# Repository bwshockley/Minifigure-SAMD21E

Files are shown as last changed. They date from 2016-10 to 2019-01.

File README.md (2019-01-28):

# Minifigure-SAMD21E
SAMD21E based Minifigure shaped development board.

## About
This circuit board was designed as a fun project for a SAMD21E microcontroller based development board.  The circuit design follows the recommended design from the SAMD Datasheet - including section 39. Schematic Checklist.  The USB protection may be overkill, but it is complete.  I made this just for fun - I am not going to provide any special support, but always welcome recommendations, suggestions, and ideas for improvements.  You are free to take it and run with it, but do not sell this design.

Order boards here:
Board 1: Stand alone - haven't tested, but should soon. [OSHPark](https://oshpark.com/shared_projects/Wh7NwFnv)

Board 2: This does not have a native USB or programming port - I am developing a backpack for it.  Will share backpack. [OSHPark](https://oshpark.com/shared_projects/W2bUXtFr)

MINI SAM TQFP SIMPLE - This version is more friendly to hand soldering with a TQFP SAMD21E chip.  USB protection and filtering removed, reset debounce removed.  [OSHPARK](https://oshpark.com/shared_projects/yFTXsDW0)

MINI SAM TQFP 1.27 SIMPLE - This version retains the TQFP SAMD21E chip, but on the back instead of the tiny 8-pin connector - I've replaced it with a 1.27mm pitch SMT connector.  Still trying to retain a "backpack" idea for add-on boards.  [OSHPARK](https://oshpark.com/shared_projects/vt6FGicv)

MINI SAM TQFP 2.54 BB (BreadBoard or Protoboard) - This version changes the rear once more to a 2.54mm pitch SMT setup for a protoboard friendly design. [OSHPARK](https://oshpark.com/shared_projects/SMD5UkUu)

Mini SAM - Protoboard - TQFP - 2017-01-17-00 - This version is similar to the other BB version, but has some refinements to layout and includes options for the onboard LED (Basic LED or the WS2812B), a plain button, and other enhancements.  [OSHPARK](https://oshpark.com/shared_projects/IhRoccbe)

Mini SAM 2017/01-001 - Latest version with minor changes and enhancements.  Once this version passes validation and verification, I will most likely archive other versions.  Details on [OSHPARK](https://oshpark.com/shared_projects/dv4tvRPH) and [here](https://github.com/bwshockley/Minifigure-SAMD21E/tree/master/board/2017/01).

----------------------------------

## Etc
The board passes all DRC for OSHPark manufacturing and should pass for most other manufacturers as well - I kept most routes, vias, etc larger than minimums and allowed plenty of space where I could.  I have tested many of these boards and all features work as designed.

## BOM
*The BOM listed at mouser is for the Mini SAM - Protoboard - TQFP - 2017-01-17-004 board.  It is a good place to start, but keep in mind you may want to change or leave out items you don't want.*

The schematic has all items listed and values and should be easily sourced.  Additionally, I have setup a [project on mouser.com that can be found here.](http://www.mouser.com/ProjectManager/ProjectDetail.aspx?AccessID=328cc4307e)  The BOM through mouser is roughly 12 USD at this time (Oct 2016).  It does not include the WS8212B 3535 LED - these can be sourced from [Adafruit](https://www.adafruit.com/products/2659) or eBay among others.  The LED does not need to be populated for the board to function, but it is fun.

## Firmware
I plan on trying to implement both Arduino and possibly Micropython on this board, but need some significant help with this.  I will update as I can.

In order to test my prototype board, I loaded the Arduino Zero bootloader, but changes the PortA pin 14 for PostA Pin 27.  Nothing else is fucntional yet - it was a bad hack to get access to the WS2812 LED for the time being and to prove to myself the board will work in theory.

(01-20-2017) FIRMWARE has been updated and almost complete.  I'm working through the last bit of verification and validation now.  Firmware and Arduino files are available in the arduino folder.  In order to burn the bootloader, the Atmel SAM-BA In-System Programmer must be installed first.

## License
Hardware - CC BY-NC 4.0 - See License file.

Software
Copyright (c) 2017 Benjamin Shockley

Permission is hereby granted, free of charge, to any person obtaining a copy
of this software and associated documentation files (the "Software"), to deal
in the Software without restriction, including without limitation the rights
to use, copy, modify, merge, publish, distribute, sublicense, and/or sell
copies of the Software, and to permit persons to whom the Software is
furnished to do so, subject to the following conditions:

The above copyright notice and this permission notice shall be included in all
copies or substantial portions of the Software.

THE SOFTWARE IS PROVIDED "AS IS", WITHOUT WARRANTY OF ANY KIND, EXPRESS OR
IMPLIED, INCLUDING BUT NOT LIMITED TO THE WARRANTIES OF MERCHANTABILITY,
FITNESS FOR A PARTICULAR PURPOSE AND NONINFRINGEMENT. IN NO EVENT SHALL THE
AUTHORS OR COPYRIGHT HOLDERS BE LIABLE FOR ANY CLAIM, DAMAGES OR OTHER
LIABILITY, WHETHER IN AN ACTION OF CONTRACT, TORT OR OTHERWISE, ARISING FROM,
OUT OF OR IN CONNECTION WITH THE SOFTWARE OR THE USE OR OTHER DEALINGS IN THE
SOFTWARE.

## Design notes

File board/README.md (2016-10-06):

#EAGLE Files
At this time I only have EAGLE files for the Minifigure Board.  If someone wants to convert them to KiCAD, I'd be happy to add those files to the repository.

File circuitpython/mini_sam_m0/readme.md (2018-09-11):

# Mini Sam M0 CircuitPython Firmware

## Source Files
Source Files Included:
- board.c
- mpconfigboard.h
- mpconfigboard.mk
- pins.c

Use these files and https://circuitpython.readthedocs.io/en/latest/ports/atmel-samd/README.html to build firmware.

## Built Firmware
- firmware.bin
- firmware.uf2

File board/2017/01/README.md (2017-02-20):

##Board 2017/01-002

This is a LEGO Minifigure sized development board using an Atmel SAMD21E 32-Bit ARM chip. I basically followed the recommended layout/setup from the SAMD21 spec sheets.

Included on Mini SAM is a WS2812B LED (STATUS) connected to PIN 27, a 0603 LED (L) connected to PIN 15, a reset button (SW1) with circuitry per datasheet connected to !RESET, and a user programmable button (SW1) that is active HIGH connected to PIN 28. The 0603 LED is connected in series with a 1Kohm resistor, part of R1, and care should be taken when selecting an 0603 LED such that at a supply of 3.3V, no more than 5mA is required.

Programming port (PROG) is a basic 10-pin SWD for ARM based processors, which is a 2x5 1.27mm pitch connector. The SWD line is pulled up with a 1Kohm resistor, part of R1.

The SDA/SCL pins are pulled high with 4.7KOhm resistors, R2, per SDA/SCL recommendations.

The voltage regulator is an MCP1700 (IC1) which is rated at 250mA at 3.3V. Plenty of current for the SAMD21E and a few other accessories such as the WS2812B.

This version has SMT layout for two single row 2.54mm pitch headers on the back. It is designed to be protoboard friendly and when populated the headers are the same width as a DIL package (7.62mm or .3") and span the center of a protoboard.

PINs 27 and 28 are not connected to the headers - due to lack of space - but instead have two pads near the bottom of the board. Reminder: PIN 27 is connected to the on-board WS2812B and PIN 28 is connected to the on-board BUTTON.

The AREF PIN - PIN AREF - has a pair of decoupling/filtering capacitors (C6, C11).

The micro-USB connector has an RC filter (R6, C13) between the case/shield of the connector and GND. If left un-populated the case/shield is an open circuit - which is the next best option. Also included is space for a USBLC6-2 (IC2) ESD protection circuit. You can bypass it by jumping PAD 1 to 6, and PAD 3 to 4, leaving the middle two PADs alone of the layout for IC2.

I have put together a sample BOM via Mouser.com which I’m including here. It can be used as a reference. Items that do not need to be populated to work: SW2812B 3535 LED, 0603 LED, SW2 (BUTTON). The SW2812B is not in the Mouser BOM - due to lack of parts. I would suggest not purchasing the 2.54mm pitch SMT male headers from Mouser, as you can find this much cheaper elsewhere. Mini SAM requires (2) 11-PIN headers. I suggest buying breakaway headers in 25-50 PIN lengths.

Arduino FIRMWARE/BOOTLOADER is complete, but I’m still testing all functions. So far all PINs work in digital setup and all analog PINs work accordingly. ANALOG and special function pins (MOSI, SDA, SCK, etc) can be accessed in Arduino by their name.

##Board 2017/01-010

This is a LEGO Minifigure sized development board using an Atmel SAMD21E 32-Bit ARM chip.  I basically followed the recommended layout/setup from the SAMD21 spec sheets.

Included on Mini SAM is a WS2812B LED pad connected to PIN 27, a 0603 LED connected to PIN 15, a reset button with support components per the datasheet, and a generic button that is active HIGH on PIN 28. The 0603 LED is connected in series with a 1Kohm resistor, part of R1, and care should be taken when selecting an 0603 LED such that at a supply of 3.3V, no more than 5mA is required.

Programming port is a standard10-pin SWD for ARM based processors, which is a 2x5 1.27mm pitch connector.  The SWD line is pulled up with a 1Kohm resistor, part of R1.  In the BOM, either purchase the 2x5 straight pin connector OR the 2x5 POGO connector and do not populate board.

The SDA/SCL pins are pulled high with 4.7KOhm resistors, R2, per SDA/SCL recommendations.

The voltage regulator is an AP2112K-3.3V which is rated at 600mA at 3.3V.  Plenty of current for the SAMD21E and a few other accessories such as the WS2812B.

This version has SMT layout for two single row 2.54mm pitch headers on the back.  It is designed to be protoboard friendly and when populated the headers are the same width as a DIL package (7.62mm or .3") and span the center of a protoboard.

PINs 27 and 28 are not connected to headers - due to lack of space - but instead have two pads near the bottom of the board.  PIN 27 is connected to the on-board WS2812B.  PIN 28 is connected to the on-board BUTTON.

The Analog Reference (PIN AREF) - has a pair of decoupling/filtering capacitors.

The micro-USB connector has an RC filter between the case/shield of the connector and GND.  If R6 and C13 are left un-populated the case/shield is an open circuit - which is the next best option.  Also included is space for a PRTR5V0U2X ESD protection circuit on USB Data lines.  This may also be left un-populated and USB will function normally.

I have put together a sample BOM via Mouser.com which I'm including here.  It can be used as a reference.  Optional, but highly recommended components: SW2812B 3535 LED, 0603 LED, SW2 (BUTTON), R4, R5, R6, C13, and PRTR5V0U2X.  R1 is for the 0603 LED and SWCLK - If not populating the 0603 LED this *may* be left un-populated as well and programming via SWD should still work as I've seen other boards without the 1Kohm resistor on SWCLK.  R2 is the 4.7Kohm pull-up resistor pair for SDA/SCL.  Many breakout boards using chips that run off SDA/SCL typically come with the 4.7Kohm pull-up resistor pair included - as such it may not be needed on Mini SAM - but it is included for ease of future components.  Please review the schematic for additional details and be aware that the BOM on Mouser.com may be out of date.  *The SW2812B is not in the Mouser BOM - due to lack of parts.*

[Mouser BOM](http://www.mouser.com/ProjectManager/ProjectDetail.aspx?AccessID=fc486f90dc)

I would suggest not purchasing the 2.54mm pitch SMT male headers from Mouser, as you can find this much cheaper elsewhere.  The best I could find on Mouser is (2) 5-Pin and (2) 6-Pin headers.  Mini SAM requires (2) 11-PIN headers.  I suggest buying breakaway headers in 25-50 PIN lengths.

Arduino FIRMWARE/BOOTLOADER is complete, but I'm still testing all functions.  So far all PINs work in digital setup and all analog PINs work accordingly.  ANALOG and special function pins (MOSI, SDA, SCK, etc) can be accessed in Arduino by their name.

Please check my Github for the latest design files and bootloade/firmware.

More details can be found on [Github](https://github.com/bwshockley/Minifigure-SAMD21E)

##Board 2017/01-012
Same as 2017/01-010 with minor cosmetic changes.

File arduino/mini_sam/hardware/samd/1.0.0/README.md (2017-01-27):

# Arduino Core for SAMD21 CPU - Mini SAM Specific

This repository contains the source code and configuration files of the Arduino Core
for Atmel's SAMD21 processor used for the Mini SAM board.

## Installation on Arduino IDE

Copy the directory [mini_sam](https://github.com/bwshockley/Minifigure-SAMD21E/new/master/arduino) to your Arduino packages directory.

## Support

Support for this repository is provided via the [Issues](https://github.com/bwshockley/Minifigure-SAMD21E/issues) page.

## Bugs or Issues

If you find a bug you can submit an issue here on github:

[https://github.com/bwshockley/Minifigure-SAMD21E/issues](https://github.com/bwshockley/Minifigure-SAMD21E/issues)

Before posting a new issue, please check if the same problem has been already reported by someone else
to avoid duplicates.

## Contributions

Contributions are always welcome. The preferred way to receive code cotribution is by submitting a 
Pull Request on github.

## License and credits

This core was developed for the Mini SAM development board and uses files and build tools from Arduino and Atmel.

```

  This library is free software; you can redistribute it and/or
  modify it under the terms of the GNU Lesser General Public
  License as published by the Free Software Foundation; either
  version 2.1 of the License, or (at your option) any later version.

  This library is distributed in the hope that it will be useful,
  but WITHOUT ANY WARRANTY; without even the implied warranty of
  MERCHANTABILITY or FITNESS FOR A PARTICULAR PURPOSE.
  See the GNU Lesser General Public License for more details.

  You should have received a copy of the GNU Lesser General Public
  License along with this library; if not, write to the Free Software
  Foundation, Inc., 51 Franklin St, Fifth Floor, Boston, MA  02110-1301  USA
```

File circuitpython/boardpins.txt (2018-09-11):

PIN     mini_sam_m0
PA00		
PA01		
PA02    ~A0
PA03									
PB08	
PB09
PA04    ~A3
PA05    ~A4
PA06    ~A1
PA07    ~A2
PA08    ~A5
PA09    A6
PA10    D1 / TX
PA11    D0 / RX
PB10
PB11	
PA12	
PA13	
PA14    D14
PA15    LED / D15
PA16    MOSI
PA17    SCK
PA18    SS / D18
PA19    MISO
PA20		
PA21		
PA22    SDA
PA23    SCL
PA24									
PA25									
PB22						
PB23							
PA27    NEOPIXEL / D27
PA28    BUTTON / D28
PA29									
PA30
PA31

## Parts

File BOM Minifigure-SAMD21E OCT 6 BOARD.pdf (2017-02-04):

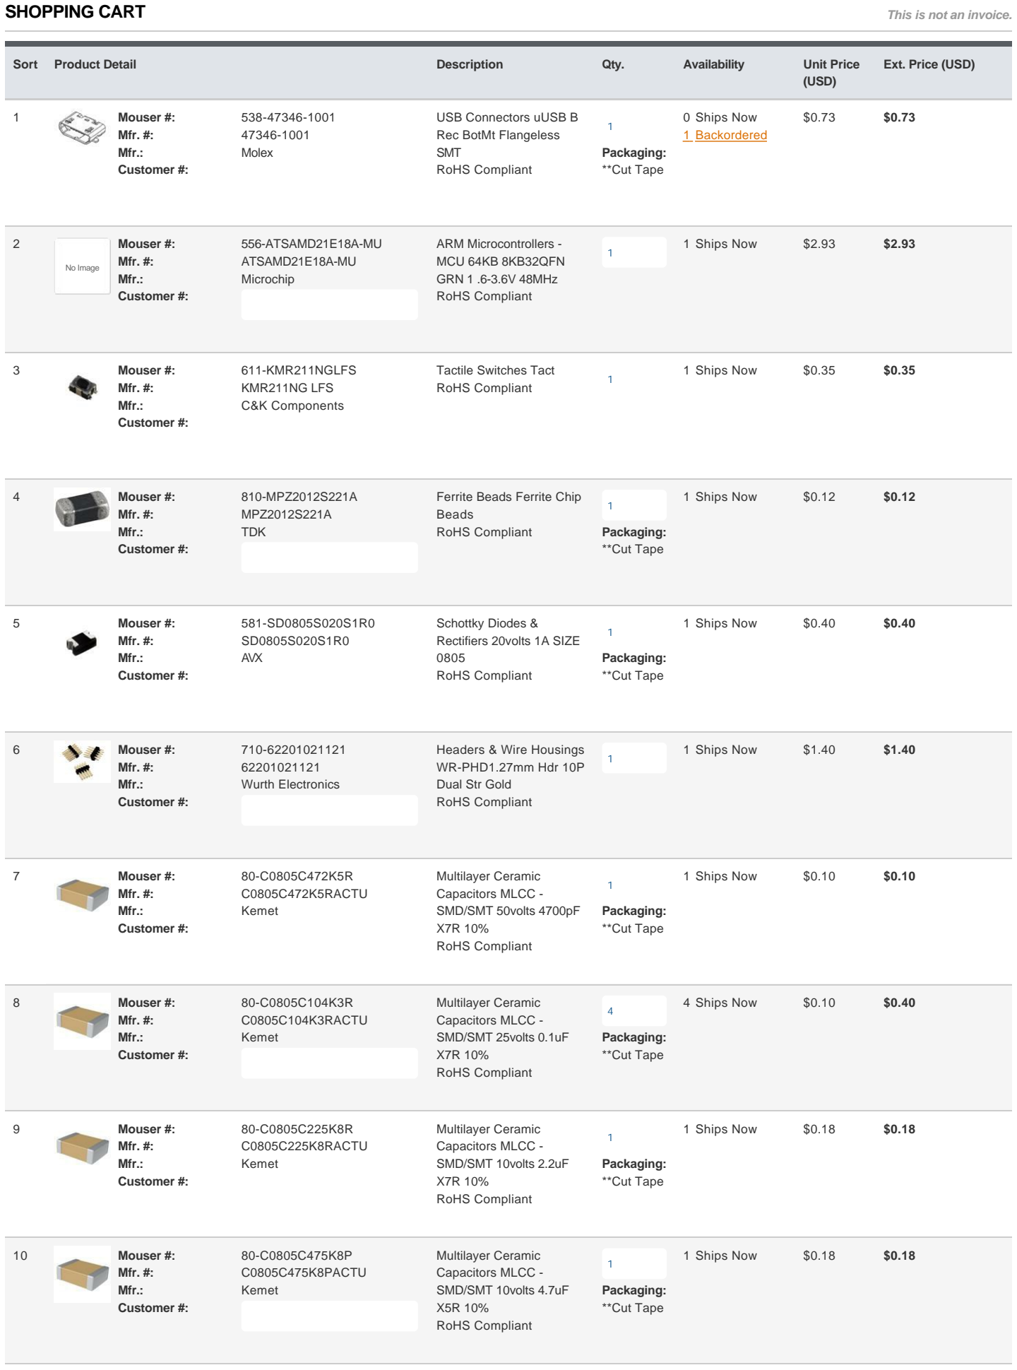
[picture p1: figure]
Sort; Product Detail; Description; Qty.; Availability; Unit Price; (USD); Ext. Price (USD); SHOPPING CART; This is not an invoice.; Mouser #:; Mfr. #:; Mfr.:; Molex; Customer #:; USB Connectors uUSB B; Rec BotMt Flangeless; SMT; RoHS Compliant; Packaging:; **Cut Tape; 0 Ships Now; 1 Backordered; No Image; 556-ATSAMD21E18A-MU; ATSAMD21E18A-MU; Microchip; ARM Microcontrollers -; MCU 64KB 8KB32QFN; GRN 1 .6-3.6V 48MHz; 1 Ships Now; 611-KMR211NGLFS; KMR211NG LFS; C&K Components; Tactile Switches Tact; 810-MPZ2012S221A; MPZ2012S221A; TDK; Ferrite Beads Ferrite Chip; Beads; AVX; Schottky Diodes &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

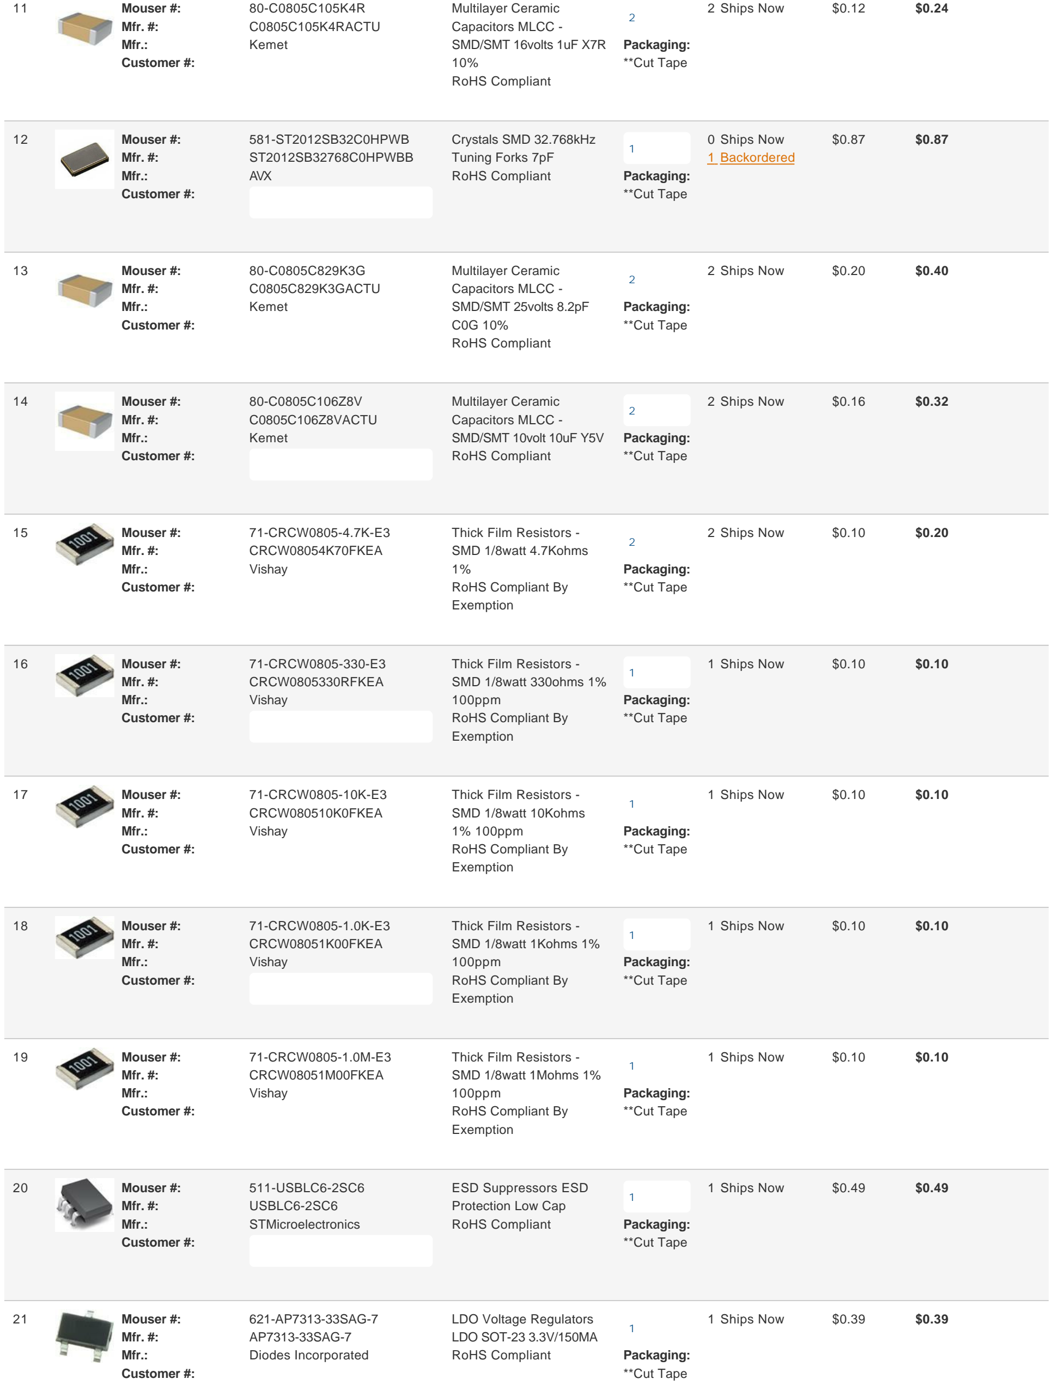
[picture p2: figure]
Mouser #:; Mfr. #:; C0805C105K4RACTU; Mfr.:; Kemet; Customer #:; Multilayer Ceramic; Capacitors MLCC -; SMD/SMT 16volts 1uF X7R; RoHS Compliant; Packaging:; **Cut Tape; 2 Ships Now; 581-ST2012SB32C0HPWB; ST2012SB32768C0HPWBB; AVX; Crystals SMD 32.768kHz; Tuning Forks 7pF; 0 Ships Now; 1 Backordered; C0805C829K3GACTU; SMD/SMT 25volts 8.2pF; C0805C106Z8VACTU; SMD/SMT 10volt 10uF Y5V; 71-CRCW0805-4.7K-E3; CRCW08054K70FKEA; Vishay; Thick Film Resistors -; SMD 1/8watt 4.7Kohms; RoHS Compliant By; Exemption; 71-CRCW0805-330-E3; CRCW0805330RFKEA; SMD 1/8watt 330ohms 1%; 100ppm; 1 Ships Now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

By submitting your order you agree to these terms and conditions. (http://www.mouser.com/saleterms) For additional information on availability, click on the Mouser Part #.

**All MouseReel™ items are noncancellable and nonreturnable.

Merchandise Total: | $10.10
Shipping Charge: | Estimate (http://www.mouser.com/EstimateShipping/ShippingEstimatorModal.aspx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)
Backorder Shipping: | Estimate (http://www.mouser.com/EstimateShipping/ShippingEstimatorModal.aspx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)

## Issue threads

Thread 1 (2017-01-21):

Beautiful Work

alwynallan, 2017-01-21:
It's the best thing shared on OSH Park recently. I hope there's a Kickstarter soon. An easy tool chain, like Teensyduino, would make it awesome, but I know it's a lot of work to create and maintain.

One little issue I noticed is the connection of the USB shield to ground. There's endless discussion in forums, with several camps:
  1. open circuit
  2. parallel RC to ground, typically 4.7nF and 1M
  3. 0603 ferrite bead to ground, they're cheap
  4. trace to ground

Since most USB Micro-B cables either don't have a shield, or don't connect it on the B side, you'll get away with 4. most times, but apparently it will not pass USB certification. For your application I would go with 1.

bwshockley, 2017-01-24:
Thanks for the suggestions.  I'll take a look.  I had, at one point, gone with option #2 - but didn't want to place too many items on the underside.  Going with option #4 would be the easiest to implement.

Closed 2017-01-26.

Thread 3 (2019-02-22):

64kb

hydronics2, 2019-02-22:
We're you able to get circuitpython on 64kb? What's the smallest you think you need. They sell the same package in 32kb and 16kb. I guess I'm also curious why you redesigned this project with the SAMD21G? thanks

bwshockley, 2019-03-12:
I was able to get it working on 64kb, but just barely.  I didn't have room for any libraries or much code space after that.  I did a redesign with the G such that I could simplify my board designs.  I have another board that uses the SAMD51G that is much more capable.  Honestly, I've put this project aside for that one as the 51G is much more capable of a chip than the 21E/G for just a little more money.  The 21G also provides enough pins to add a 2MB memory chip to the board for loading more libraries and code.

hydronics2, 2019-03-14:
yea, tell me about it. I finally got the 21E up and running with 32kB of flash. Fine for 8bit architecture but not for 32bit SAMD21 architecture!! About 50 lines of simple code uses 332 bytes (12%) in for the UNO but compiles over 9,000 bytes (9248 bytes (56%)) for the SAMD21E15, SAMD21E16, SAMD21E17, etc

I guess there is a fair about of "fixed overhead" (an empty Zero sketch is 10k.

I wonder if the Adafruit circuit python will accept larger memory chip than 2MB flash chip?

bwshockley, 2019-03-27:
Oh - the 2MB chip I used was based on physical size/space on the minifigure board.  I used a 2mm x 3mm uson chip that maxed out at 2MB from Winbond, but there were other options around that size physically.  Anything larger and the physical size of the chip went up or got really complex (BGAs) etc.

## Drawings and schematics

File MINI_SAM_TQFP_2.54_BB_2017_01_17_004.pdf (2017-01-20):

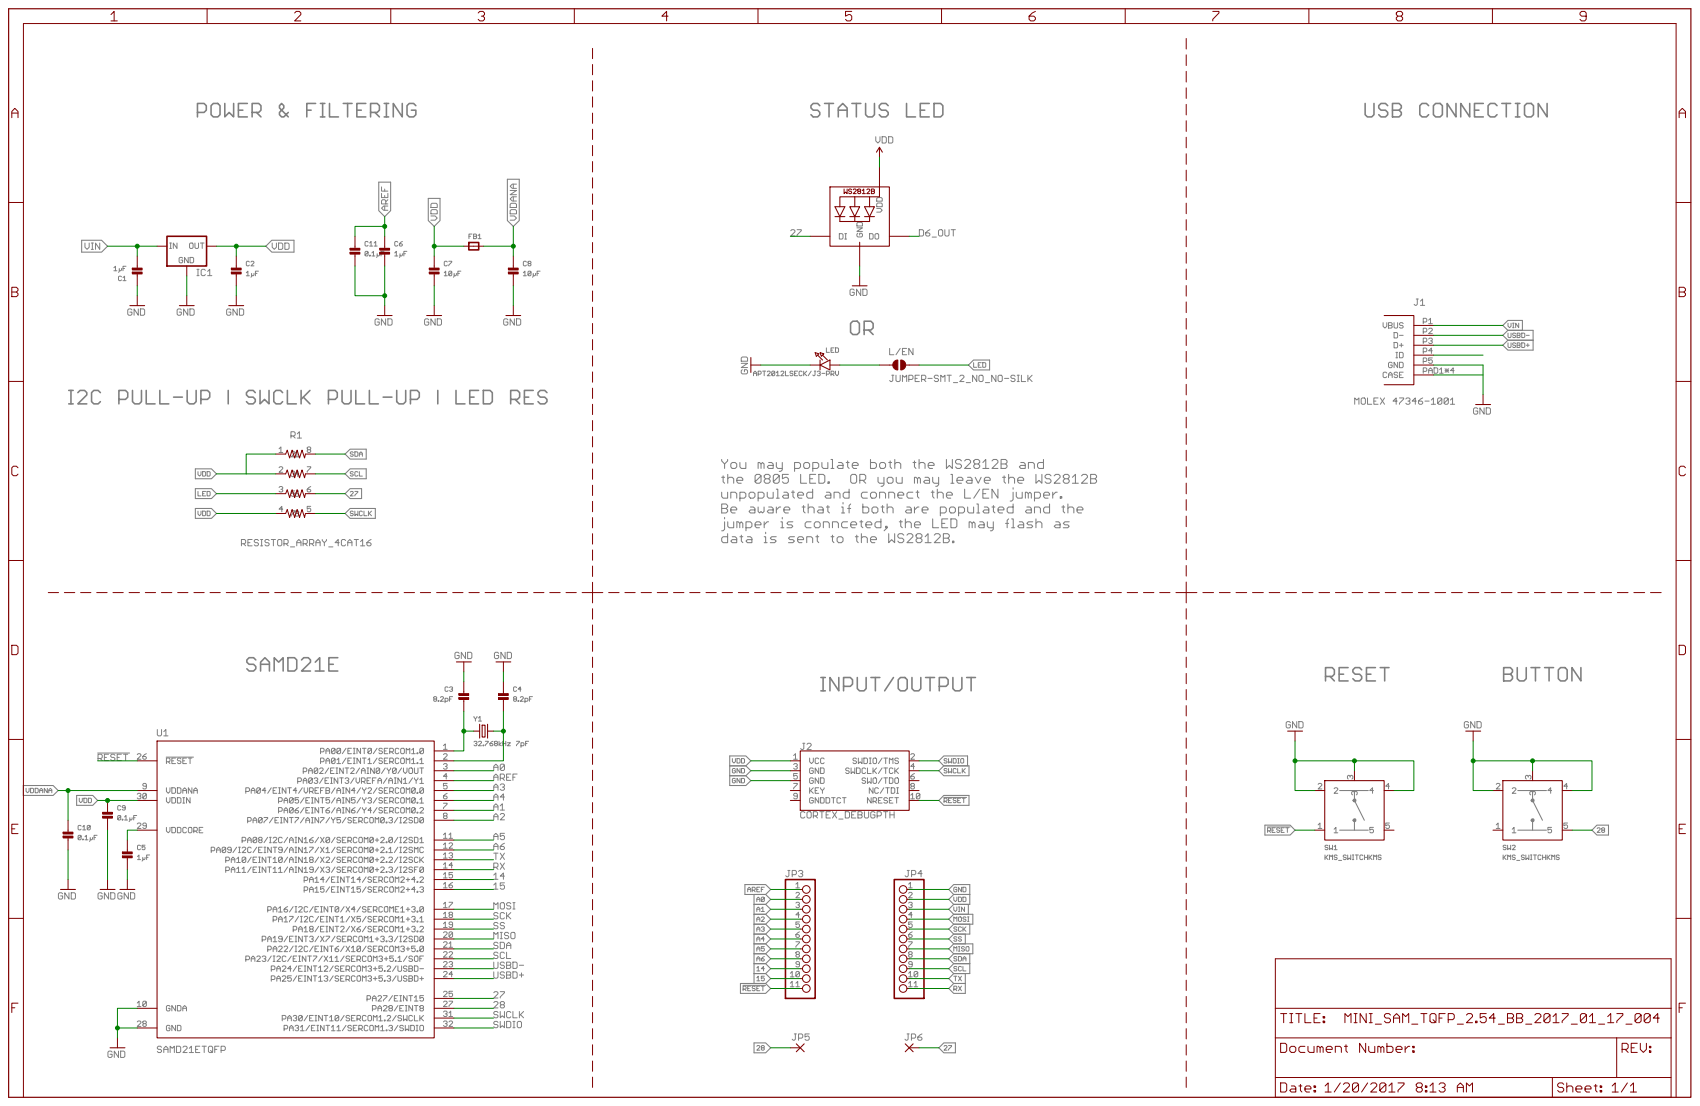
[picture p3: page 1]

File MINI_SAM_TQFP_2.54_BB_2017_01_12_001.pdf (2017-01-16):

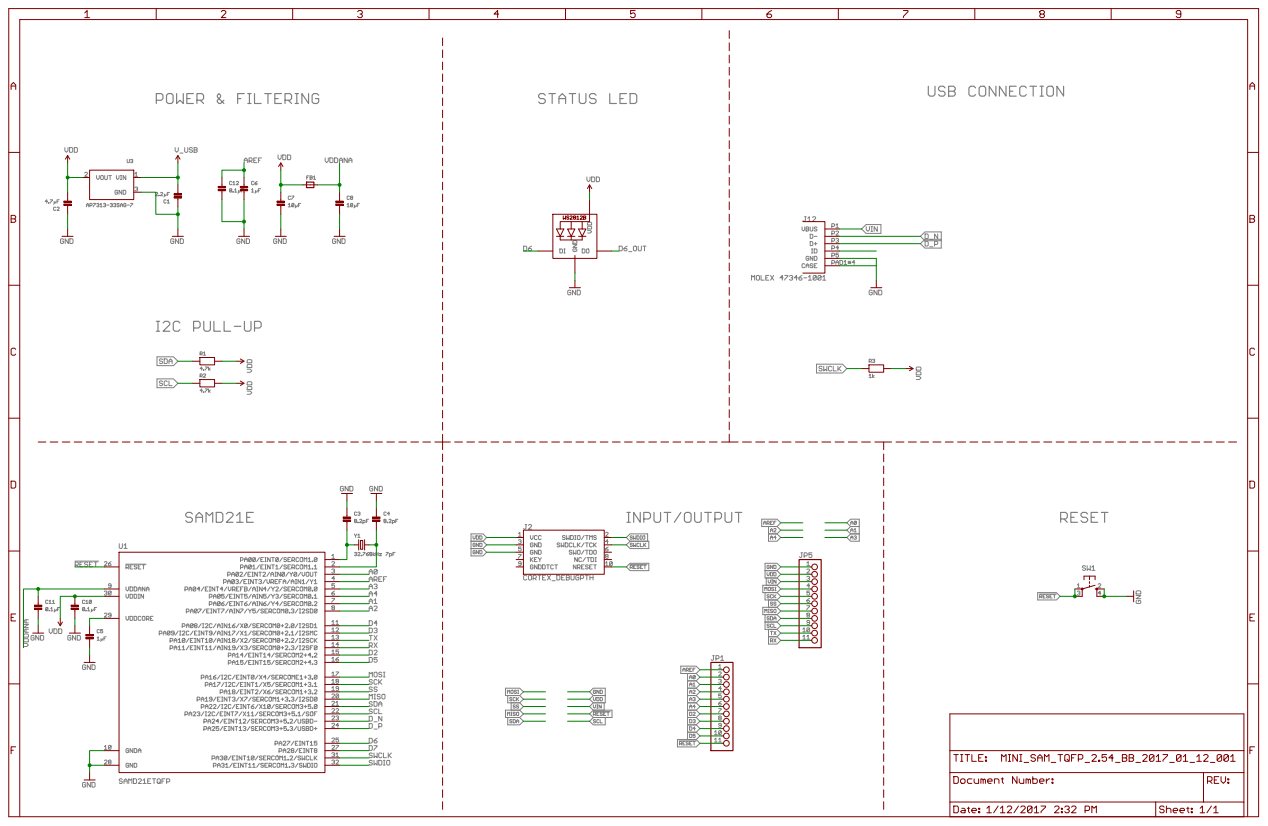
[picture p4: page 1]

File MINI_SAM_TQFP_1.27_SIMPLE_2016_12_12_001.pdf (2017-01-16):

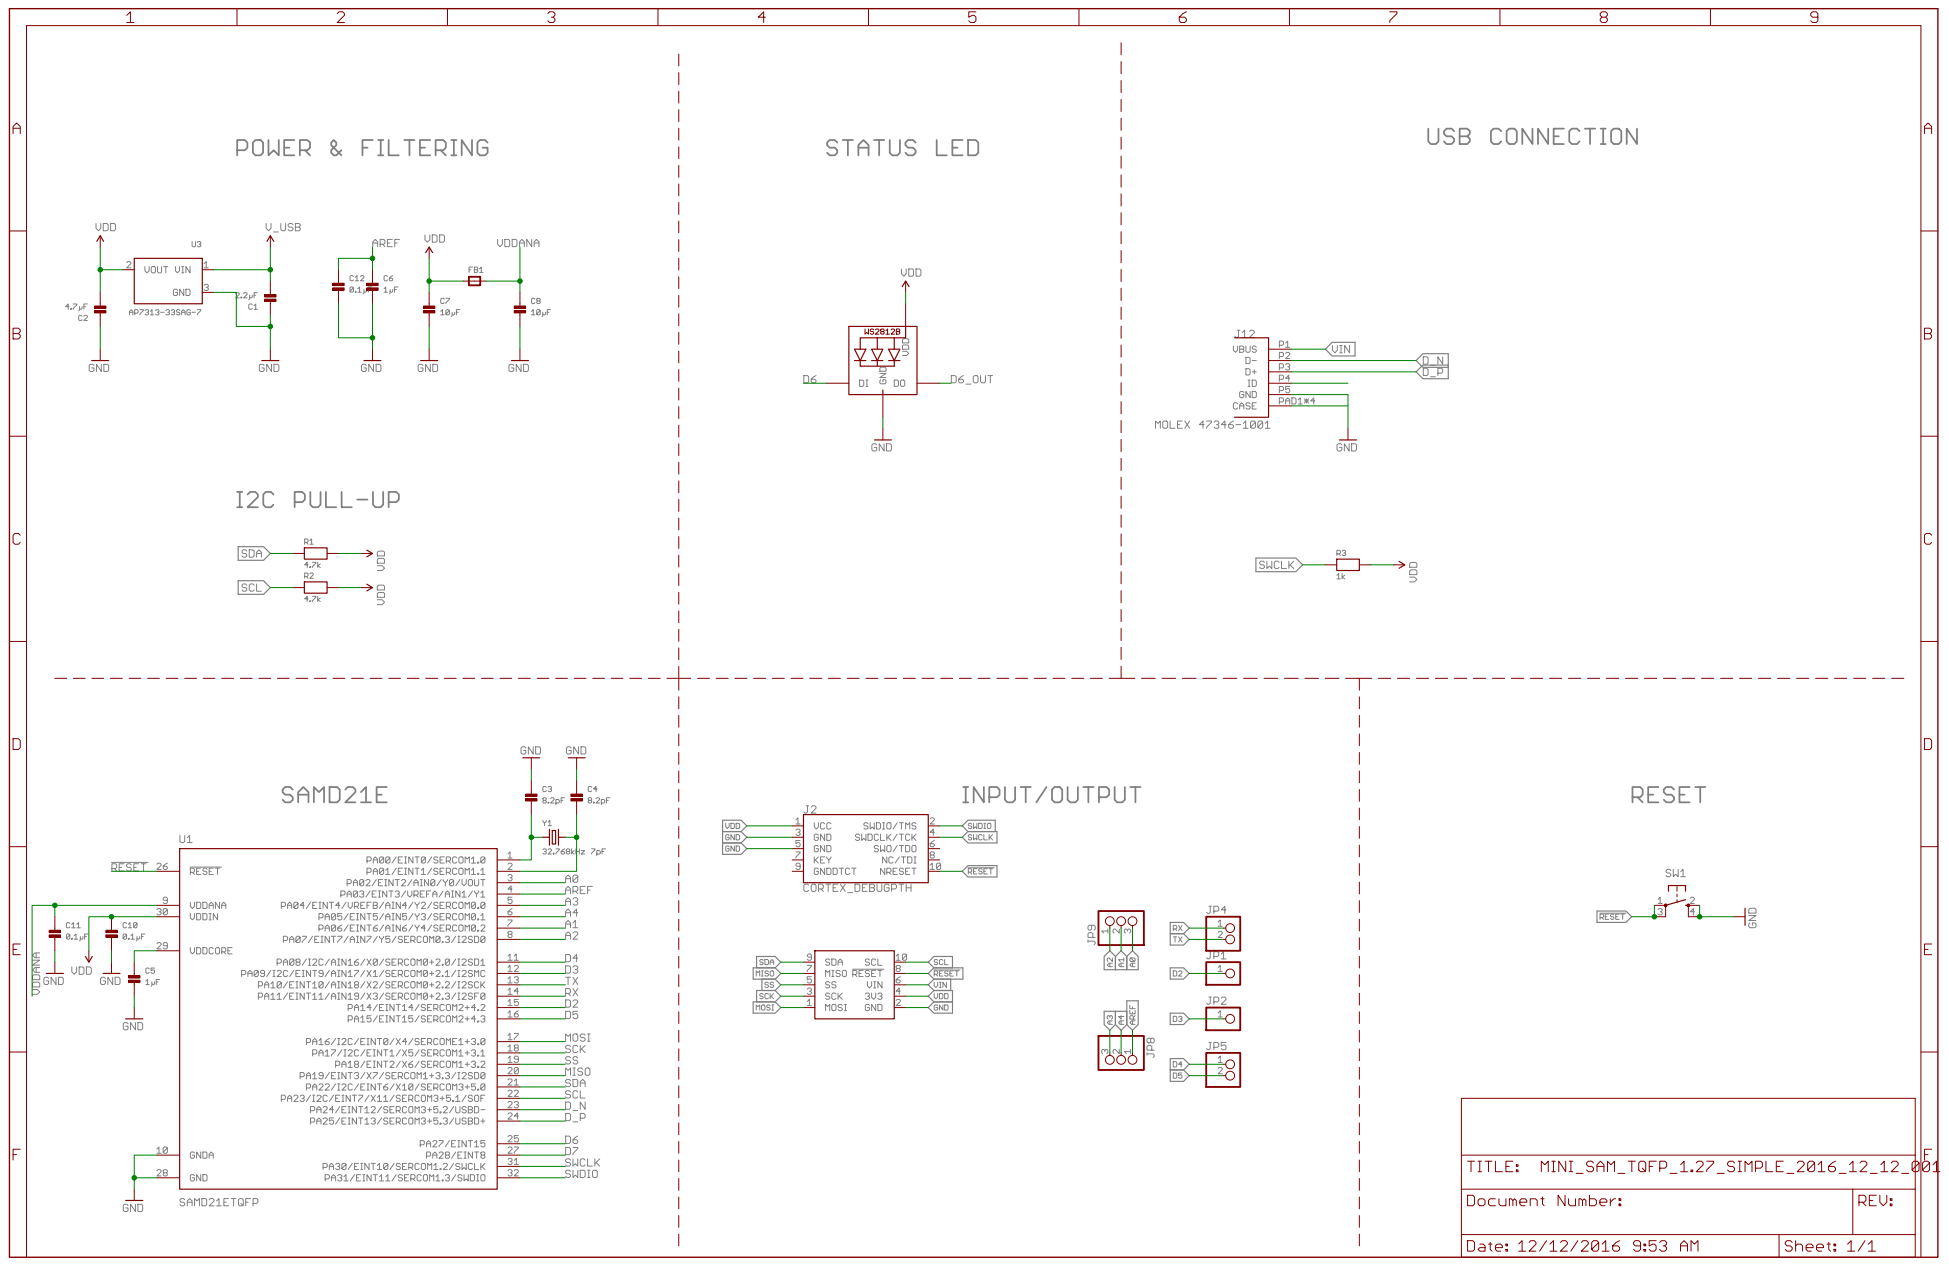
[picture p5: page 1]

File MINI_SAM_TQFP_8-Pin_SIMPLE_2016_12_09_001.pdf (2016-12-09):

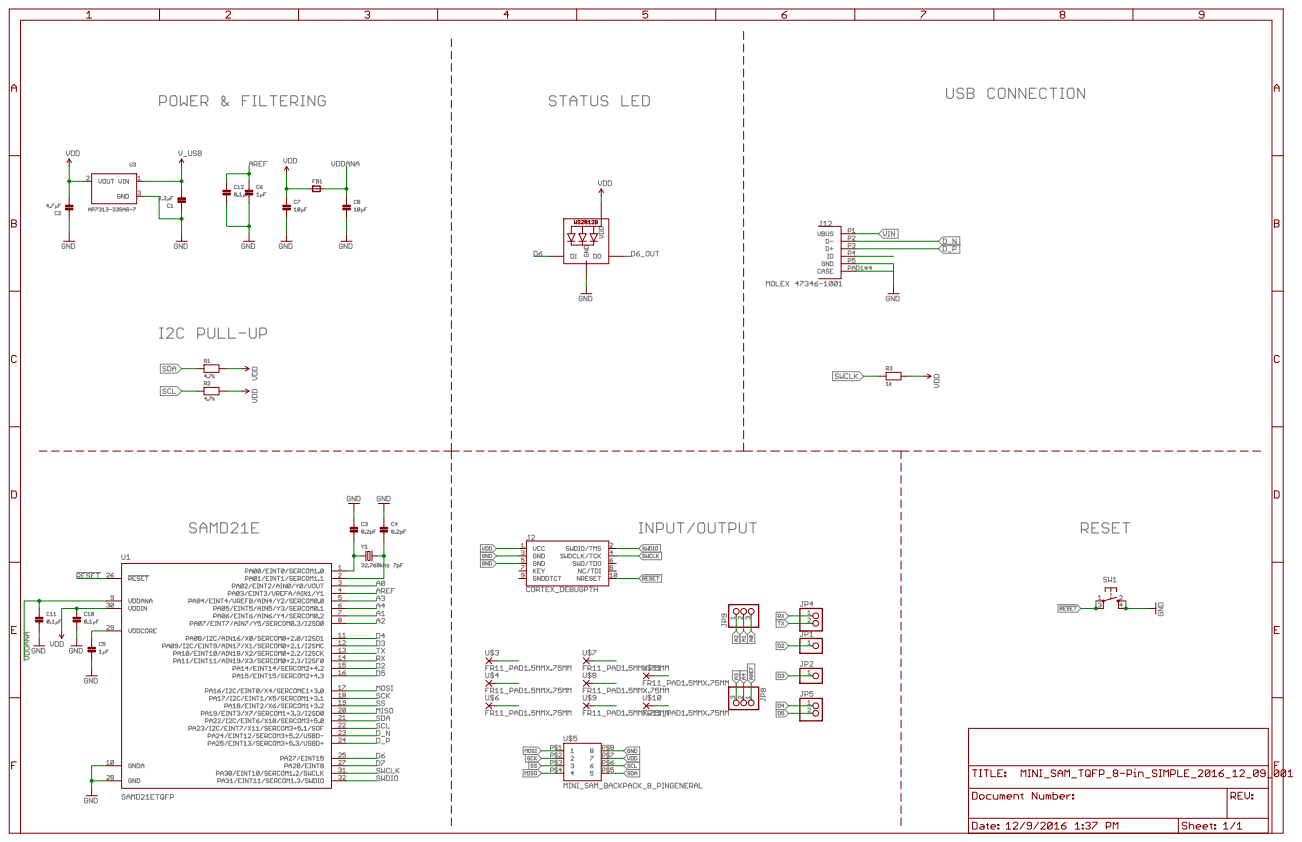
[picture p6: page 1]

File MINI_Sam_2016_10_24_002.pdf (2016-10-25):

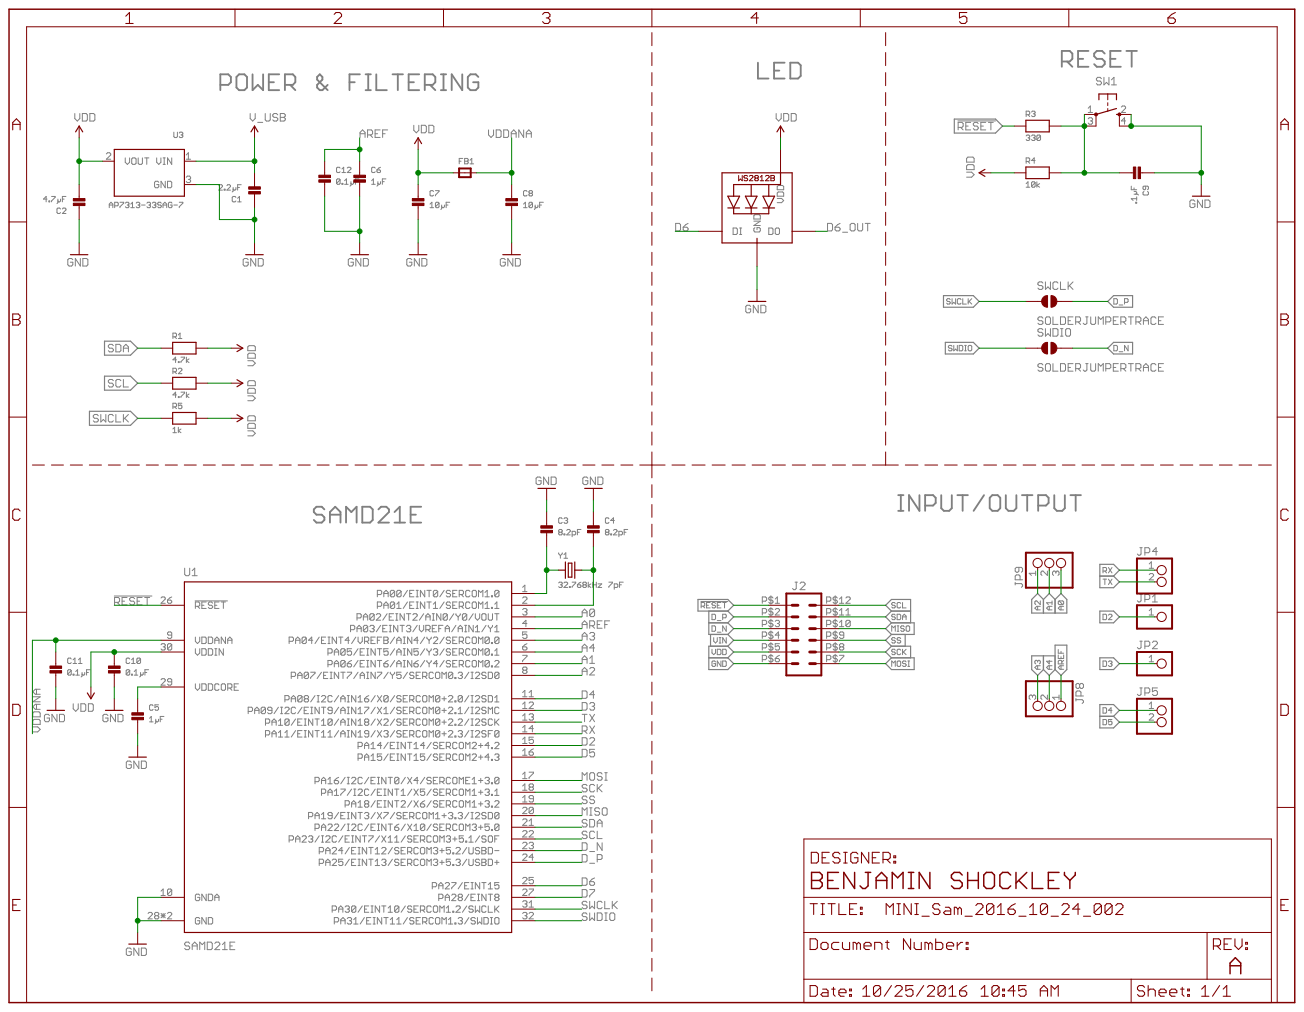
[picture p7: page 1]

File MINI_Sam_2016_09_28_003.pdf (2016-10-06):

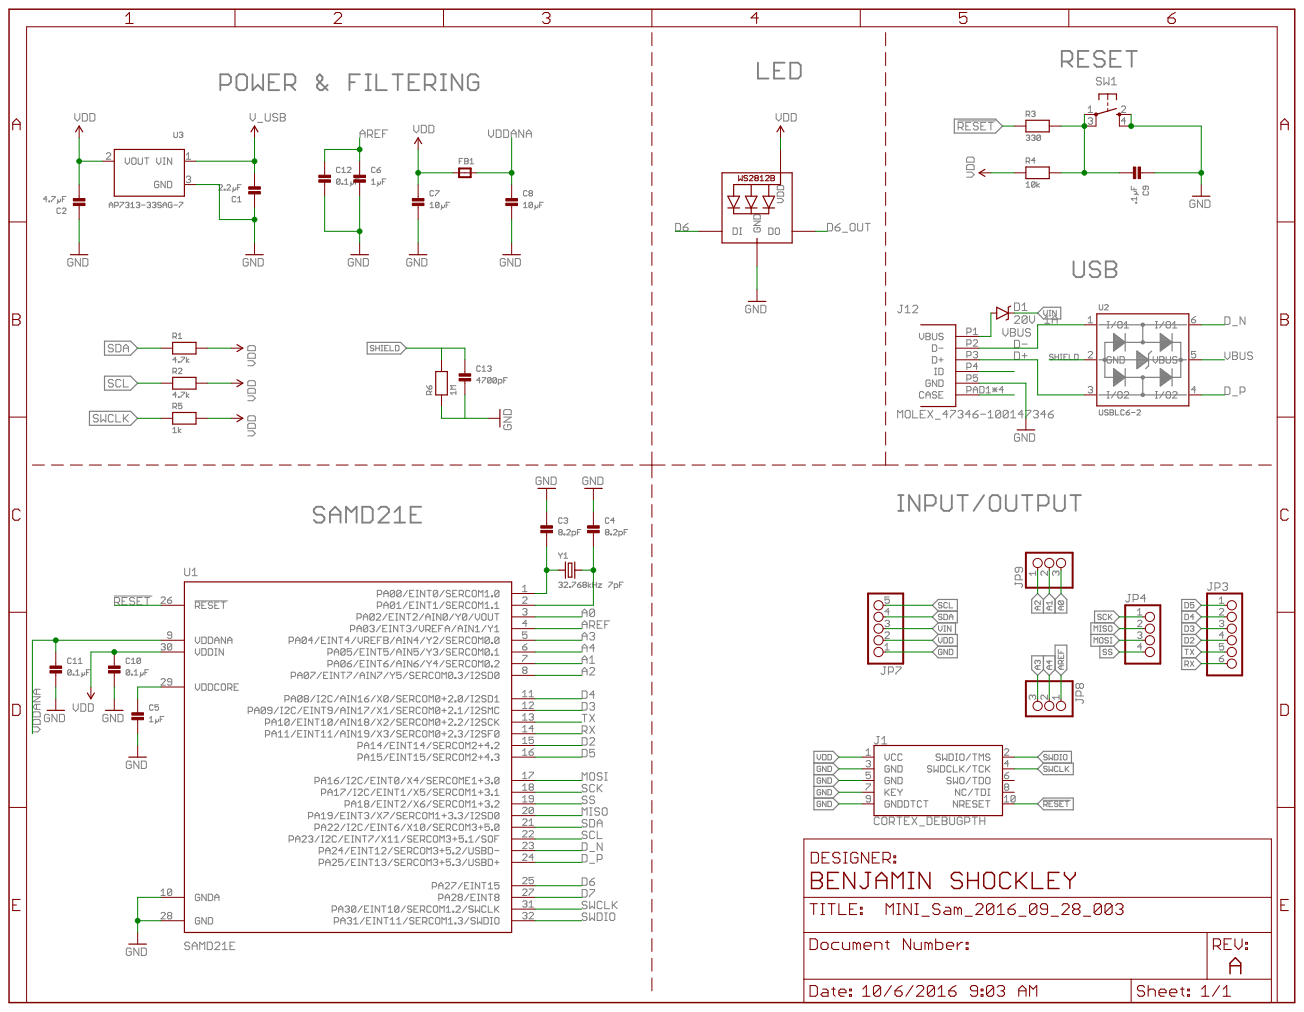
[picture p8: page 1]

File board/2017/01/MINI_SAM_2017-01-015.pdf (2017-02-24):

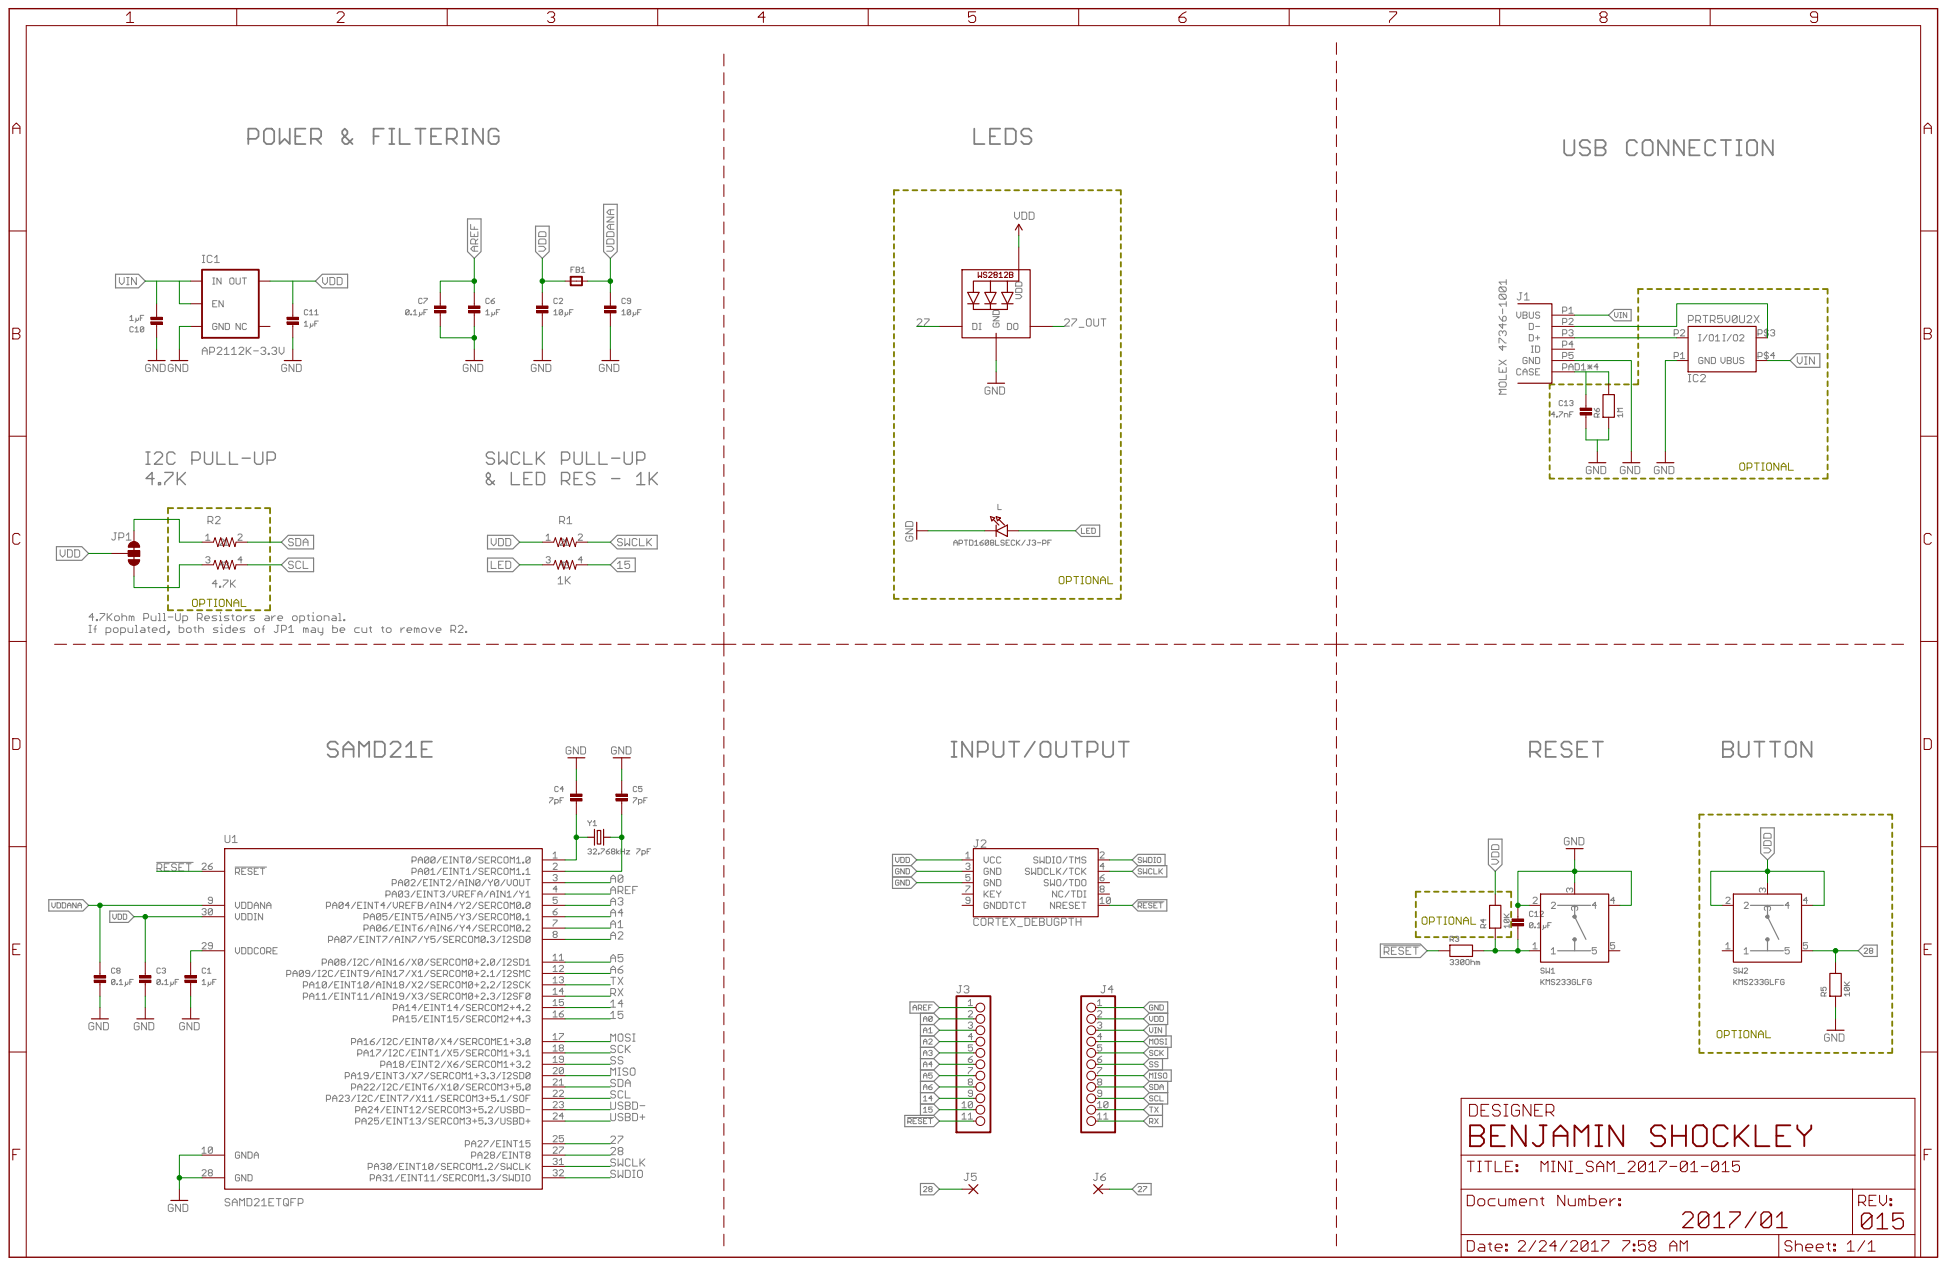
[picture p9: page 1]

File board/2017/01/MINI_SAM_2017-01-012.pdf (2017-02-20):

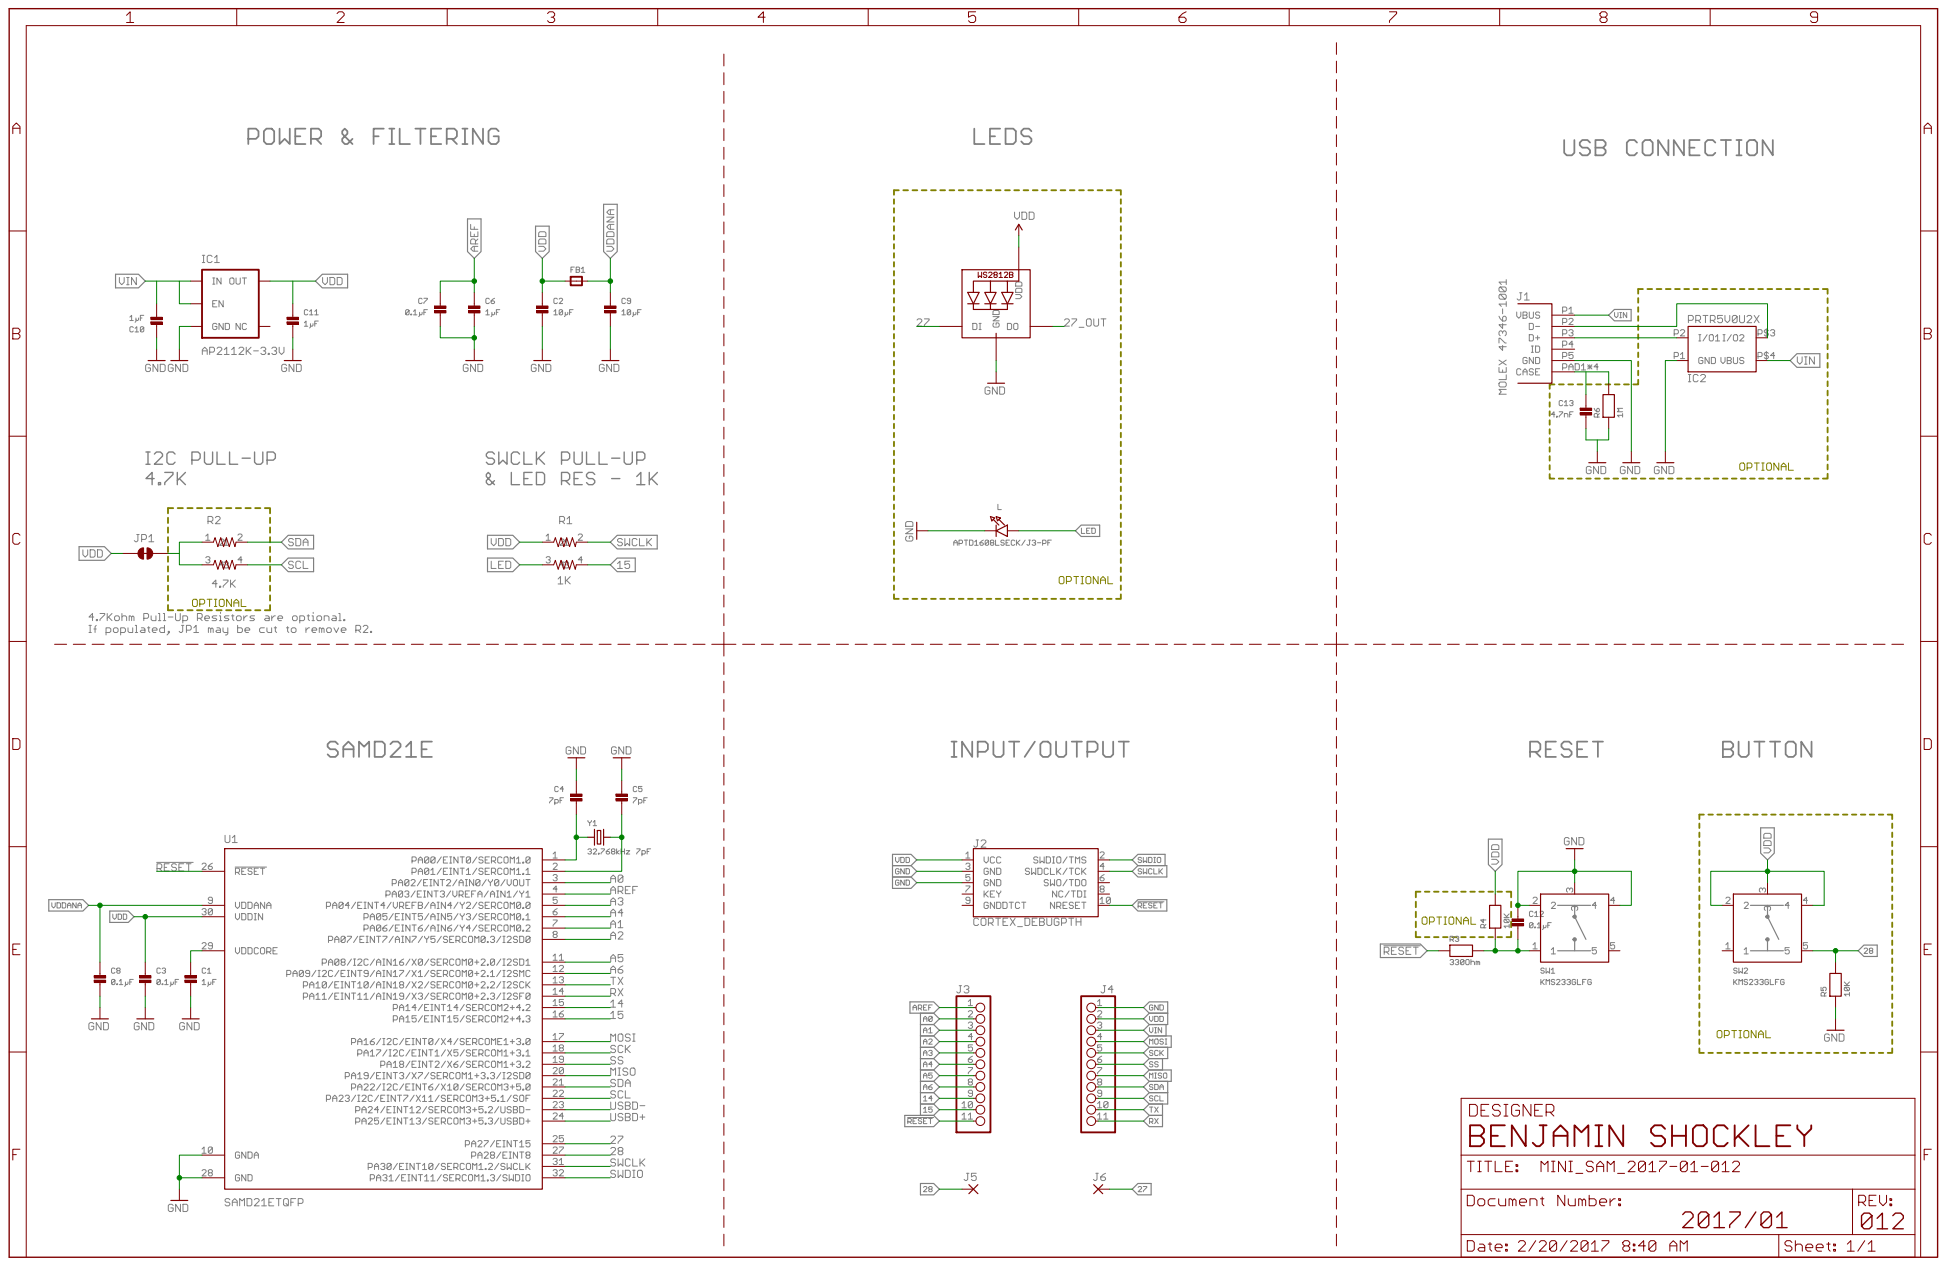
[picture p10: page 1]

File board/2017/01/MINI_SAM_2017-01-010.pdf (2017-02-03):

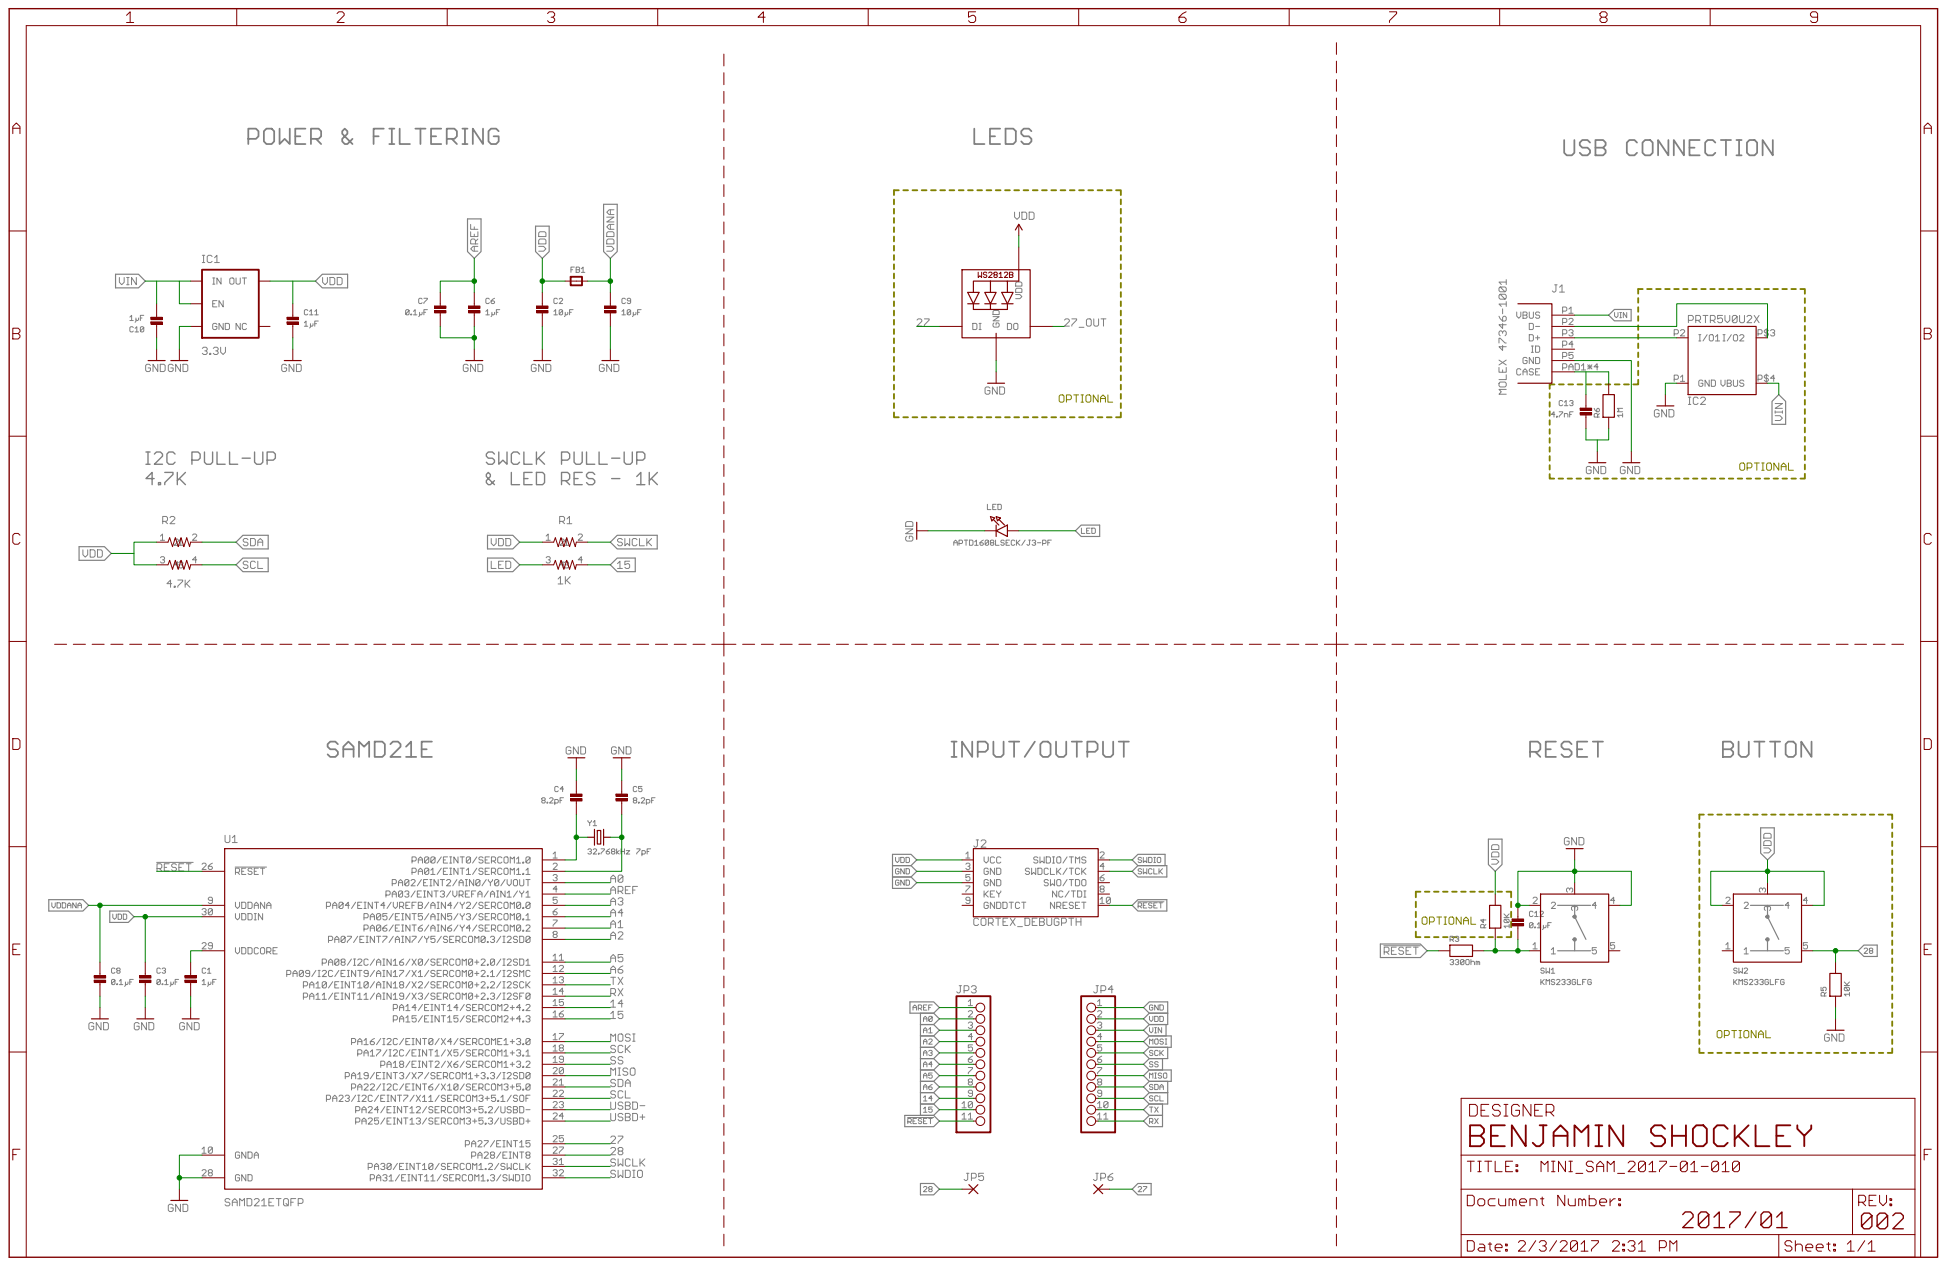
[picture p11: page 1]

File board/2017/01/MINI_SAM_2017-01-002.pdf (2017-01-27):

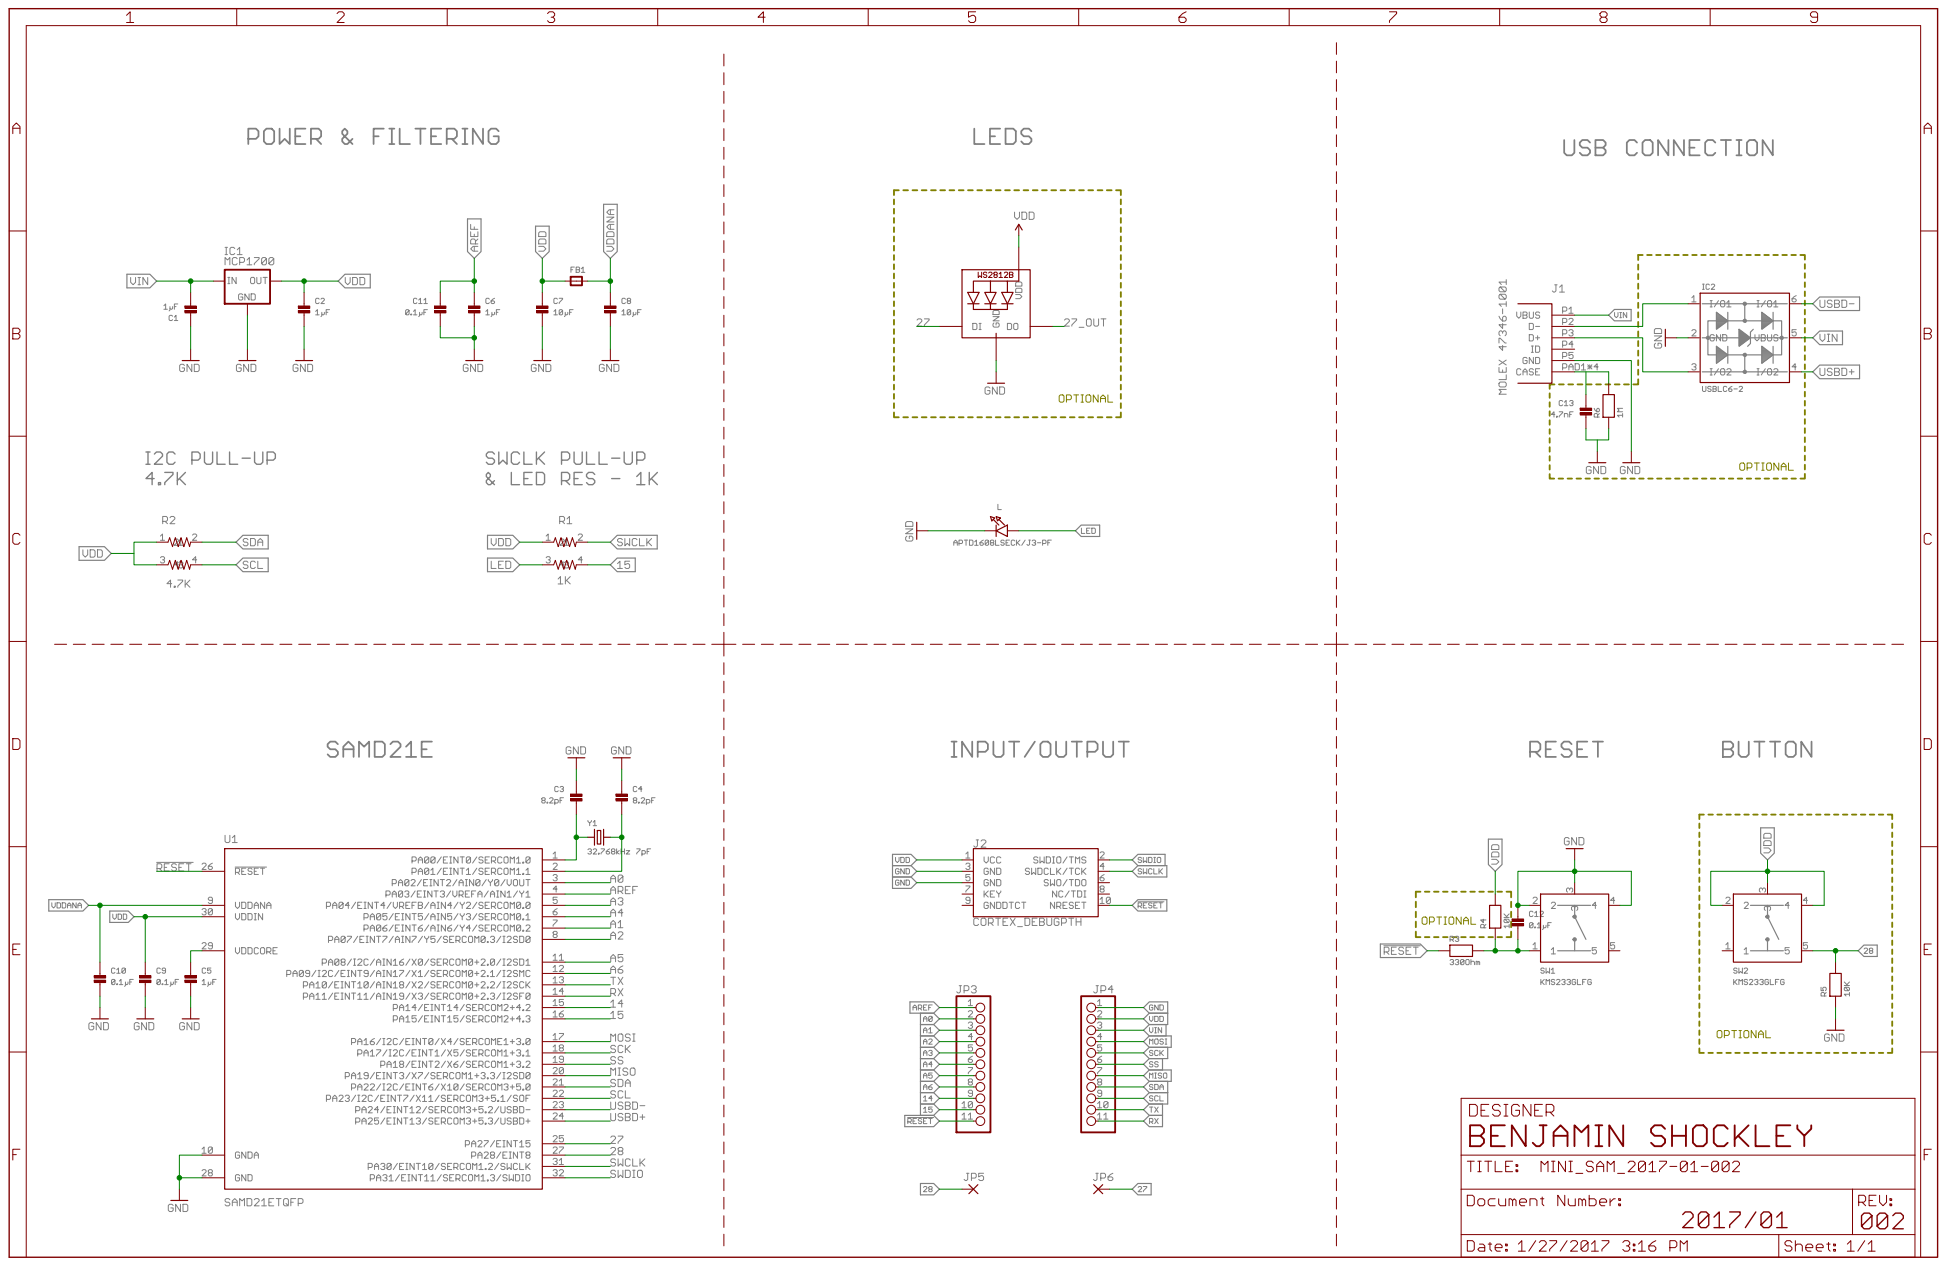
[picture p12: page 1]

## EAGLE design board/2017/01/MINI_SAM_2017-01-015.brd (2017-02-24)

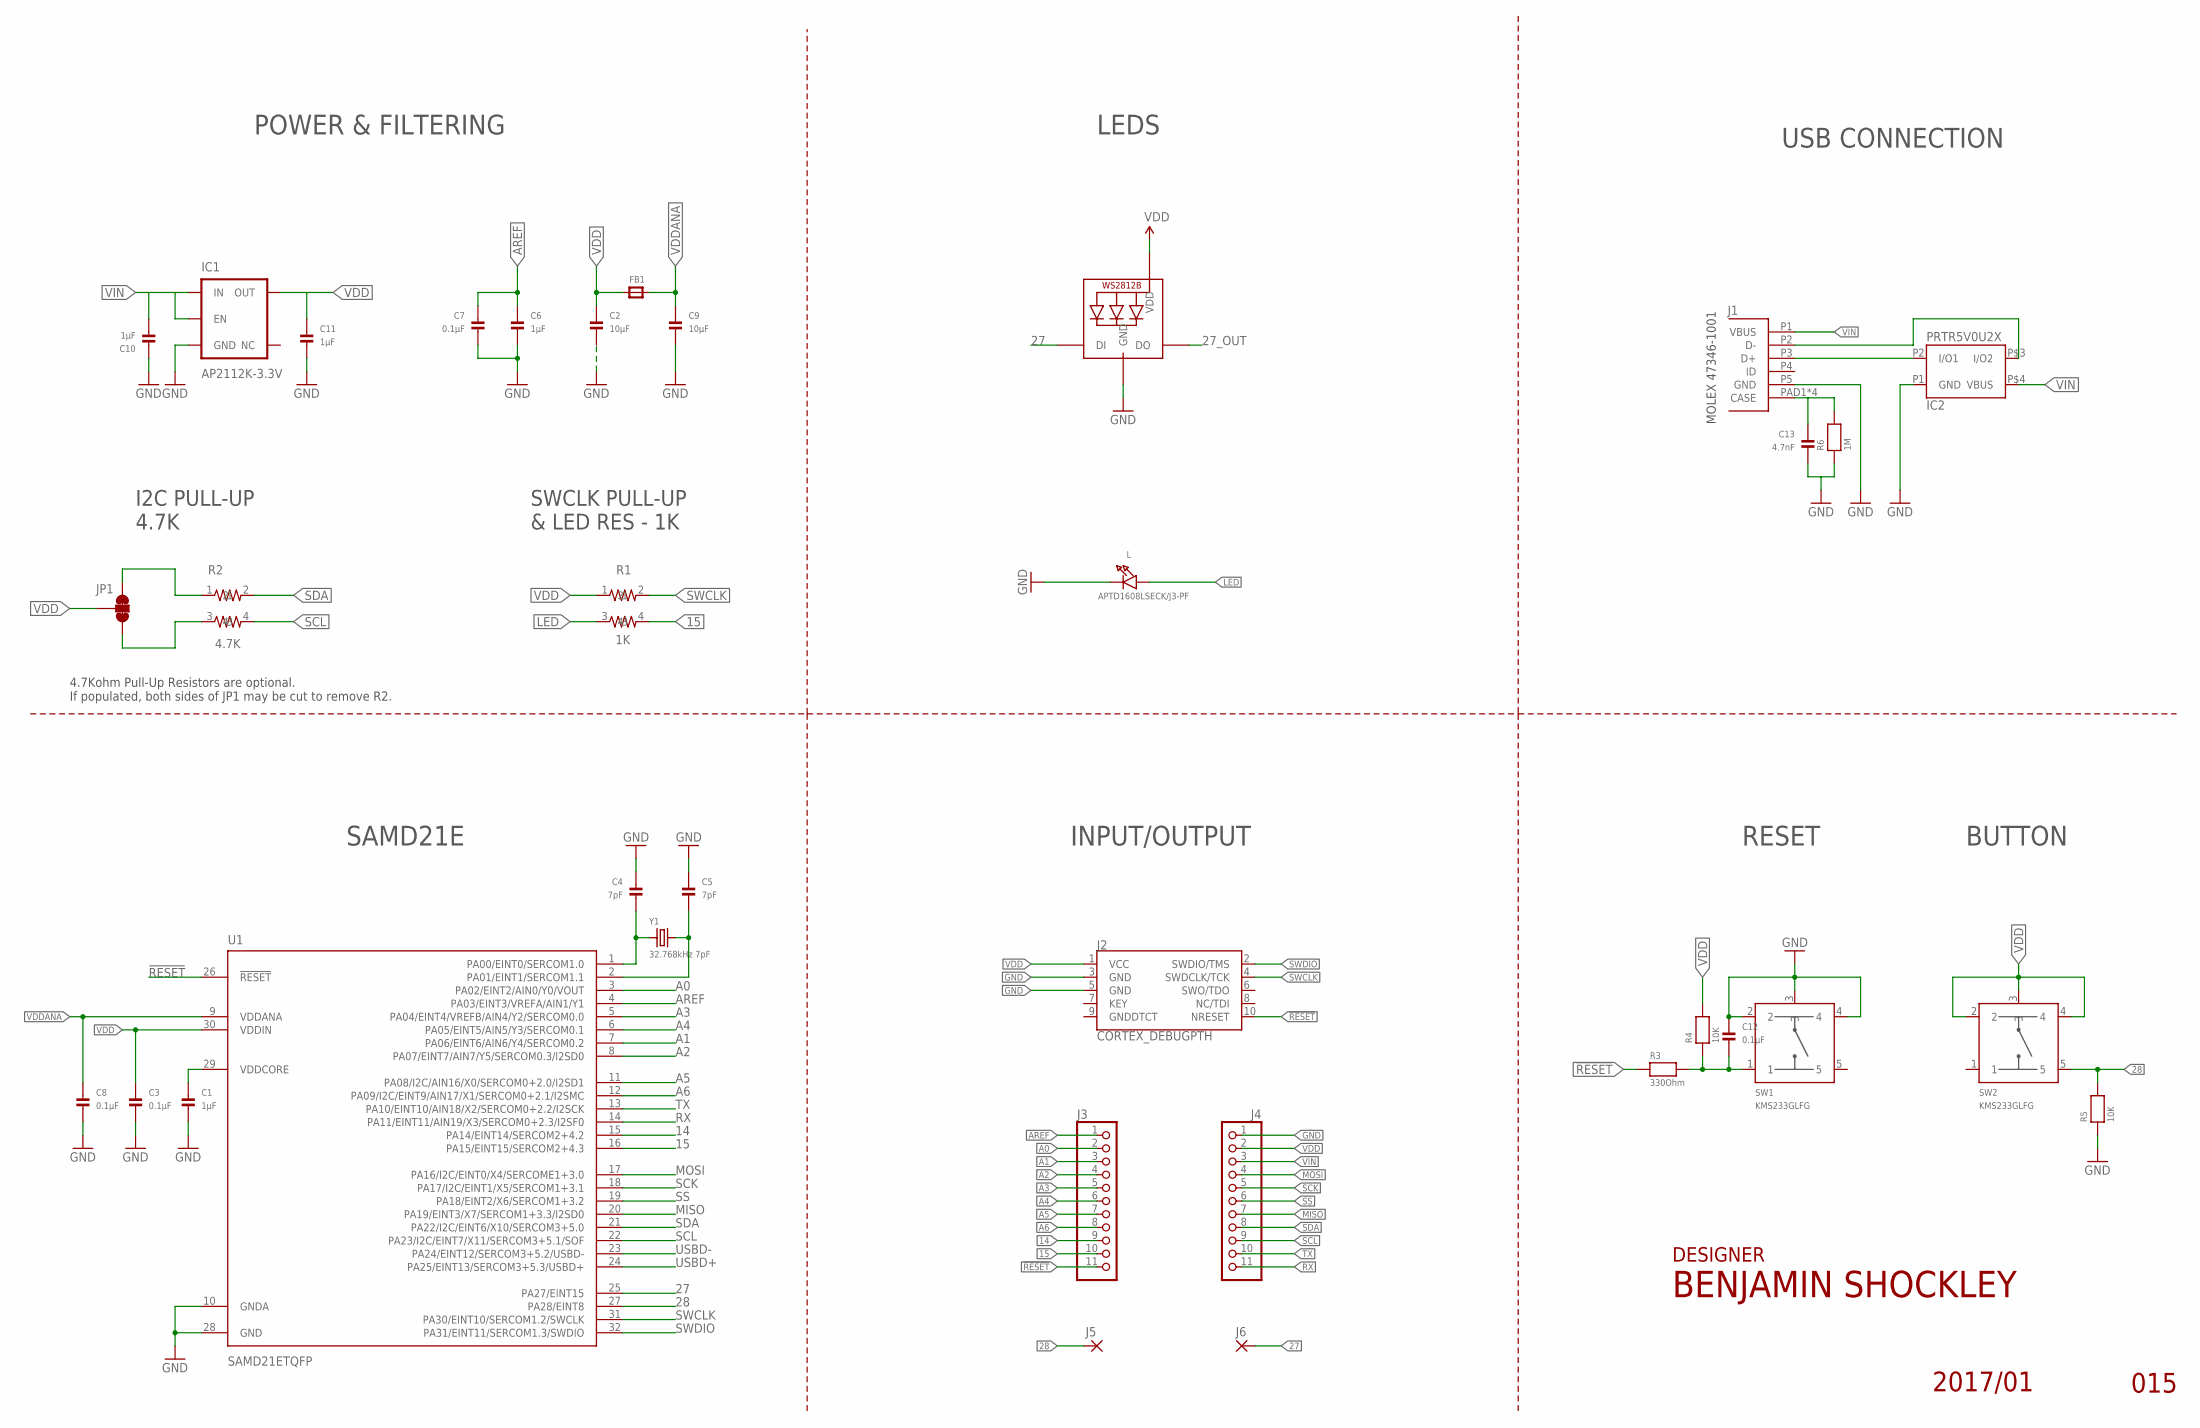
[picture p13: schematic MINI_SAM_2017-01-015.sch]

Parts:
C1, C6, C10, C11: 1µF; _0805MP
C2, C9: 10µF; _0805MP
C3, C7, C8, C12: 0.1µF; _0805MP
C4, C5: 7pF; _0805MP
C13: 4.7nF; _0805MP
FB1: FERRITE_0805MP; _0805MP
IC1: AP2112K-3.3V; SOT23-5
IC2: PRTR5V0U2X; SOT143B_REFLOW
J1: MOLEX_47346-100147346; MOLEX_47346-1001
J2: CORTEX_DEBUGPTH; 2X5-PTH-1.27MM
J3, J4: PINHD-1X111X11_SMT; 1X11_SMT
J5, J6: FR11_PAD2MMX1MM; SMD2MMX1MM
JP1: JUMPER-SMT_3_2-NC_TRACE_NO-SILK; SMT-JUMPER_3_2-NC_TRACE_NO-SILK
L: APTD1608LSECK/J3-PF; CHIPLED_0603_NOOUTLINE
R1: 1K; RESISTOR_ARRAY_0606
R2: 4.7K; RESISTOR_ARRAY_0606
R3: 330Ohm; _0805MP
R4, R5: 10K; _0805MP
R6: 1M; _0805MP
STATUS: WS2812B3535; LED3535
SW1, SW2: KMS233GLFG; KMS_SWITCH
U1: SAMD21ETQFP; TQFP32-08
Y1: 32.768kHz 7pF; _0805MP

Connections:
14: J3.9, U1.15 (PA14/EINT14/SERCOM2+4.2)
15: J3.10, R1.4, U1.16 (PA15/EINT15/SERCOM2+4.3)
27: J6.P$1, STATUS.1 (DI), U1.25 (PA27/EINT15)
27_OUT: STATUS.3 (DO)
28: J5.P$1, R5.2, SW2.5, U1.27 (PA28/EINT8)
!RESET: J2.10 (NRESET), J3.11, R3.1, U1.26 (!RESET)
A0: J3.2, U1.3 (PA02/EINT2/AIN0/Y0/VOUT)
A1: J3.3, U1.7 (PA06/EINT6/AIN6/Y4/SERCOM0.2)
A2: J3.4, U1.8 (PA07/EINT7/AIN7/Y5/SERCOM0.3/I2SD0)
A3: J3.5, U1.5 (PA04/EINT4/VREFB/AIN4/Y2/SERCOM0.0)
A4: J3.6, U1.6 (PA05/EINT5/AIN5/Y3/SERCOM0.1)
A5: J3.7, U1.11 (PA08/I2C/AIN16/X0/SERCOM0+2.0/I2SD1)
A6: J3.8, U1.12 (PA09/I2C/EINT9/AIN17/X1/SERCOM0+2.1/I2S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)
AREF: C6.1, C7.1, J3.1, U1.4 (PA03/EINT3/VREFA/AIN1/Y1)
GND: C1.2, C2.2, C3.2, C4.1, C5.1, C6.2, C7.2, C8.2, C9.2, C10.1, C11.2, C12.1, C13.2, IC1.2 (GND), IC2.P1 (GND), J1.P5 (GND), J2.3 (GND), J2.5 (GND), J4.1, L.C, R5.1, R6.1, STATUS.4 (GND), SW1.2, SW1.3, SW1.4, U1.10 (GNDA), U1.28 (GND)
LED: L.A, R1.3
MISO: J4.7, U1.20 (PA19/EINT3/X7/SERCOM1+3.3/I2SD0)
MOSI: J4.4, U1.17 (PA16/I2C/EINT0/X4/SERCOME1+3.0)
unnamed: C4.2, U1.1 (PA00/EINT0/SERCOM1.0), Y1.1
unnamed: C13.1, J1.PAD1 (CASE), J1.PAD2 (CASE), J1.PAD3 (CASE), J1.PAD4 (CASE), R6.2
unnamed: JP1.1, R2.1
unnamed: C12.2, R3.2, R4.1, SW1.1
unnamed: C5.2, U1.2 (PA01/EINT1/SERCOM1.1), Y1.2
unnamed: JP1.3, R2.3
unnamed: C1.1, U1.29 (VDDCORE)
RX: J4.11, U1.14 (PA11/EINT11/AIN19/X3/SERCOM0+2.3/I2SF0)
SCK: J4.5, U1.18 (PA17/I2C/EINT1/X5/SERCOM1+3.1)
SCL: J4.9, R2.4, U1.22 (PA23/I2C/EINT7/X11/SERCOM3+5.1/SOF)
SDA: J4.8, R2.2, U1.21 (PA22/I2C/EINT6/X10/SERCOM3+5.0)
SS: J4.6, U1.19 (PA18/EINT2/X6/SERCOM1+3.2)
SWCLK: J2.4 (SWDCLK/TCK), R1.2, U1.31 (PA30/EINT10/SERCOM1.2/SWCLK)
SWDIO: J2.2 (SWDIO/TMS), U1.32 (PA31/EINT11/SERCOM1.3/SWDIO)
TX: J4.10, U1.13 (PA10/EINT10/AIN18/X2/SERCOM0+2.2/I2SCK)
USBD+: IC2.P2 (I/O1), J1.P3 (D+), U1.24 (PA25/EINT13/SERCOM3+5.3/USBD+)
USBD-: IC2.P$3 (I/O2), J1.P2 (D-), U1.23 (PA24/EINT12/SERCOM3+5.2/USBD-)
VDD: C2.1, C3.1, C11.1, FB1.1, IC1.5 (OUT), J2.1 (VCC), J4.2, JP1.2, R1.1, R4.2, STATUS.2 (VDD), SW2.2, SW2.3, SW2.4, U1.30 (VDDIN)
VDDANA: C8.1, C9.1, FB1.2, U1.9 (VDDANA)
VIN: C10.2, IC1.1 (IN), IC1.3 (EN), IC2.P$4 (VBUS), J1.P1 (VBUS), J4.3

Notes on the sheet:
INPUT/OUTPUT
RESET
POWER & FILTERING
SAMD21E
LEDS
USB CONNECTION
I2C PULL-UP 4.7K
MOLEX 47346-1001
BUTTON
SWCLK PULL-UP & LED RES - 1K
DESIGNER
4.7Kohm Pull-Up Resistors are optional. If populated, both sides of JP1 may be cut to remove R2.

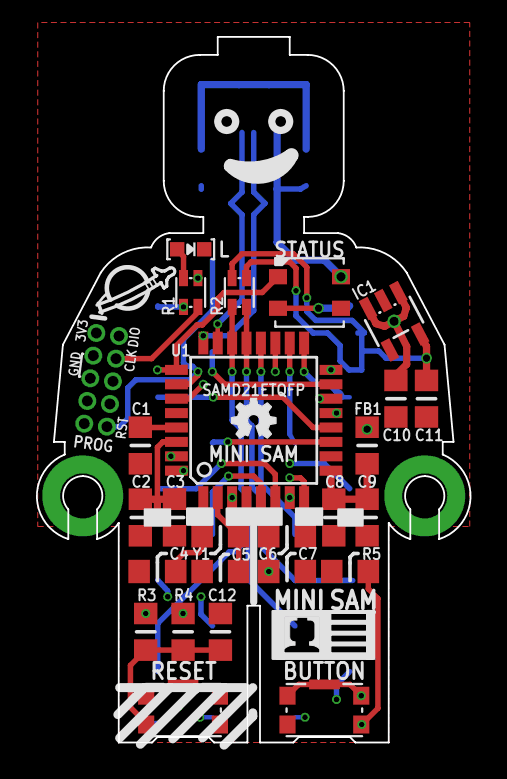
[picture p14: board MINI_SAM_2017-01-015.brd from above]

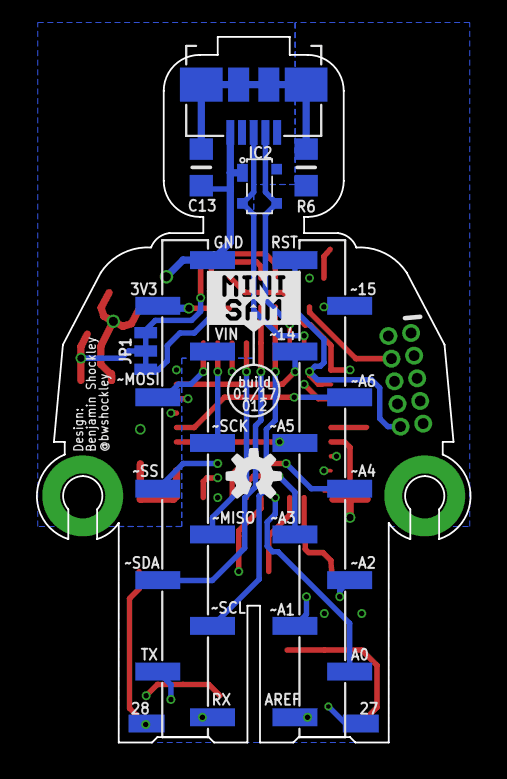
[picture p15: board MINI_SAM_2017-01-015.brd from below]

Board: 4 copper layers, 24.1 x 39.2 mm, 37 parts (10 on the bottom side), 37 nets.

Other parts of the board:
U$1: OSHW-LOGO-MINI
U$3: OSHW-LOGO-S

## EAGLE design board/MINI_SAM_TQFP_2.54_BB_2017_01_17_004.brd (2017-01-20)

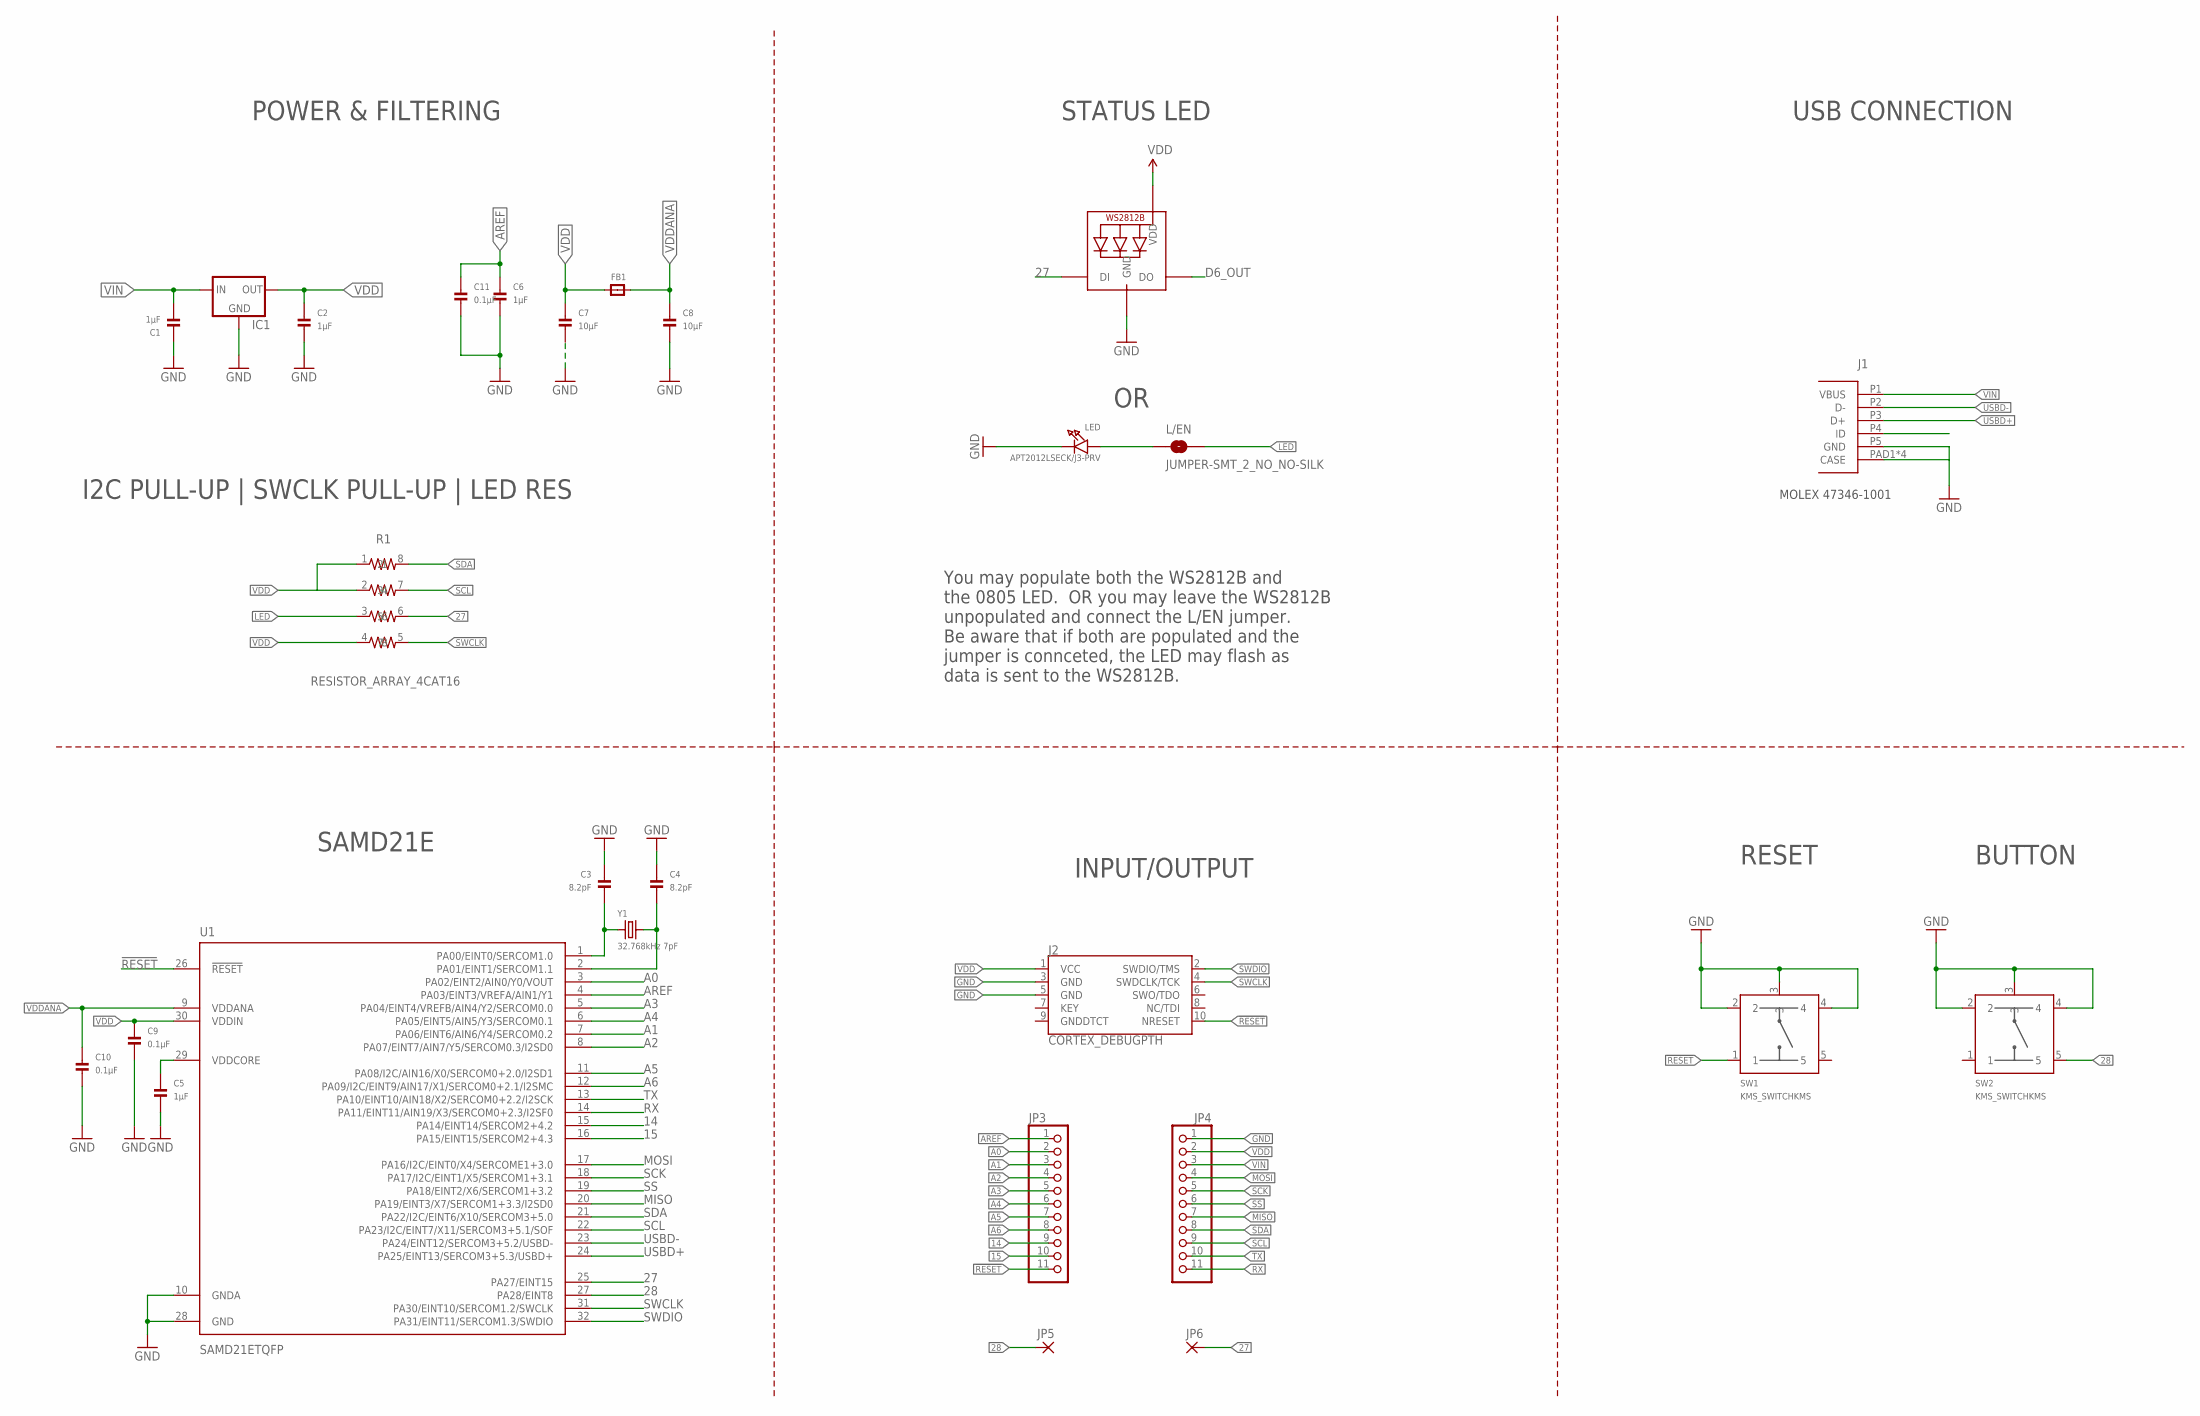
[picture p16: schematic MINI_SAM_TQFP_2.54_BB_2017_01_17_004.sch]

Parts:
C1, C2, C5, C6: 1µF; _0805MP
C3, C4: 8.2pF; _0805MP
C7, C8: 10µF; _0805MP
C9, C10, C11: 0.1µF; _0805MP
FB1: FERRITE_0805MP; _0805MP
IC1: MCP1700; SOT23
J1: MOLEX_47346-100147346; MOLEX_47346-1001
J2: CORTEX_DEBUGPTH; 2X5-PTH-1.27MM
JP3, JP4: PINHD-1X111X11_SMT; 1X11_SMT
JP5, JP6: FR11_PAD2.5MMX1.5MM; SMD2.5MMX1.5MM
L/EN: JUMPER-SMT_2_NO_NO-SILK; SMT-JUMPER_2_NO_NO-SILK
LED: APT2012LSECK/J3-PRV; CHIPLED_0805_NOOUTLINE
R1: RESISTOR_ARRAY_4CAT16; CAT16_ARRAY
STATUS: WS2812B3535; LED3535
SW1, SW2: KMS_SWITCHKMS; KMS_SWITCH
U1: SAMD21ETQFP; TQFP32-08
Y1: 32.768kHz 7pF; _0805MP

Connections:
14: JP3.9, U1.15 (PA14/EINT14/SERCOM2+4.2)
15: JP3.10, U1.16 (PA15/EINT15/SERCOM2+4.3)
27: JP6.P$1, R1.6 (5), STATUS.1 (DI), U1.25 (PA27/EINT15)
28: JP5.P$1, SW2.5, U1.27 (PA28/EINT8)
!RESET: J2.10 (NRESET), JP3.11, SW1.1, U1.26 (!RESET)
A0: JP3.2, U1.3 (PA02/EINT2/AIN0/Y0/VOUT)
A1: JP3.3, U1.7 (PA06/EINT6/AIN6/Y4/SERCOM0.2)
A2: JP3.4, U1.8 (PA07/EINT7/AIN7/Y5/SERCOM0.3/I2SD0)
A3: JP3.5, U1.5 (PA04/EINT4/VREFB/AIN4/Y2/SERCOM0.0)
A4: JP3.6, U1.6 (PA05/EINT5/AIN5/Y3/SERCOM0.1)
A5: JP3.7, U1.11 (PA08/I2C/AIN16/X0/SERCOM0+2.0/I2SD1)
A6: JP3.8, U1.12 (PA09/I2C/EINT9/AIN17/X1/SERCOM0+2.1/I2S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)
AREF: C6.1, C11.1, JP3.1, U1.4 (PA03/EINT3/VREFA/AIN1/Y1)
D6_OUT: STATUS.3 (DO)
GND: C1.1, C2.2, C3.1, C4.1, C5.2, C6.2, C7.2, C8.2, C9.2, C10.2, C11.2, IC1.1 (GND), J1.P5 (GND), J1.PAD1 (CASE), J1.PAD2 (CASE), J1.PAD3 (CASE), J1.PAD4 (CASE), J2.3 (GND), J2.5 (GND), JP4.1, LED.C, STATUS.4 (GND), SW1.2, SW1.3, SW1.4, SW2.2, SW2.3, SW2.4, U1.10 (GNDA), U1.28 (GND)
LED: L/EN.2, R1.3 (6)
MISO: JP4.7, U1.20 (PA19/EINT3/X7/SERCOM1+3.3/I2SD0)
MOSI: JP4.4, U1.17 (PA16/I2C/EINT0/X4/SERCOME1+3.0)
unnamed: C3.2, U1.1 (PA00/EINT0/SERCOM1.0), Y1.1
unnamed: L/EN.1, LED.A
unnamed: C4.2, U1.2 (PA01/EINT1/SERCOM1.1), Y1.2
unnamed: C5.1, U1.29 (VDDCORE)
RX: JP4.11, U1.14 (PA11/EINT11/AIN19/X3/SERCOM0+2.3/I2SF0)
SCK: JP4.5, U1.18 (PA17/I2C/EINT1/X5/SERCOM1+3.1)
SCL: JP4.9, R1.7 (3), U1.22 (PA23/I2C/EINT7/X11/SERCOM3+5.1/SOF)
SDA: JP4.8, R1.8 (2), U1.21 (PA22/I2C/EINT6/X10/SERCOM3+5.0)
SS: JP4.6, U1.19 (PA18/EINT2/X6/SERCOM1+3.2)
SWCLK: J2.4 (SWDCLK/TCK), R1.5 (7), U1.31 (PA30/EINT10/SERCOM1.2/SWCLK)
SWDIO: J2.2 (SWDIO/TMS), U1.32 (PA31/EINT11/SERCOM1.3/SWDIO)
TX: JP4.10, U1.13 (PA10/EINT10/AIN18/X2/SERCOM0+2.2/I2SCK)
USBD+: J1.P3 (D+), U1.24 (PA25/EINT13/SERCOM3+5.3/USBD+)
USBD-: J1.P2 (D-), U1.23 (PA24/EINT12/SERCOM3+5.2/USBD-)
VDD: C2.1, C7.1, C9.1, FB1.1, IC1.2 (OUT), J2.1 (VCC), JP4.2, R1.1, R1.2 (4), R1.4 (8), STATUS.2 (VDD), U1.30 (VDDIN)
VDDANA: C8.1, C10.1, FB1.2, U1.9 (VDDANA)
VIN: C1.2, IC1.3 (IN), J1.P1 (VBUS), JP4.3

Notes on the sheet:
INPUT/OUTPUT
RESET
POWER & FILTERING
SAMD21E
STATUS LED
USB CONNECTION
I2C PULL-UP | SWCLK PULL-UP | LED RES
MOLEX 47346-1001
You may populate both the WS2812B and the 0805 LED. OR you may leave the WS2812B unpopulated and connect the L/EN jumper. Be aware that if both are populated and the jumper is connceted, the LED may flash as data is sent to the WS2812B.
BUTTON

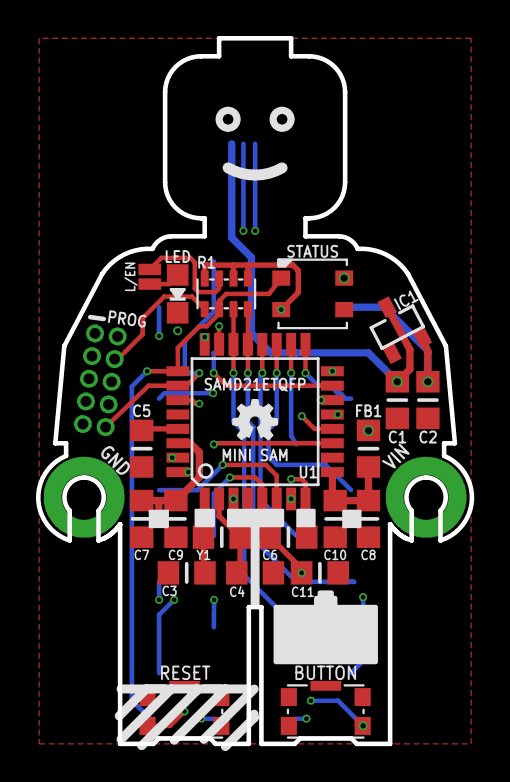
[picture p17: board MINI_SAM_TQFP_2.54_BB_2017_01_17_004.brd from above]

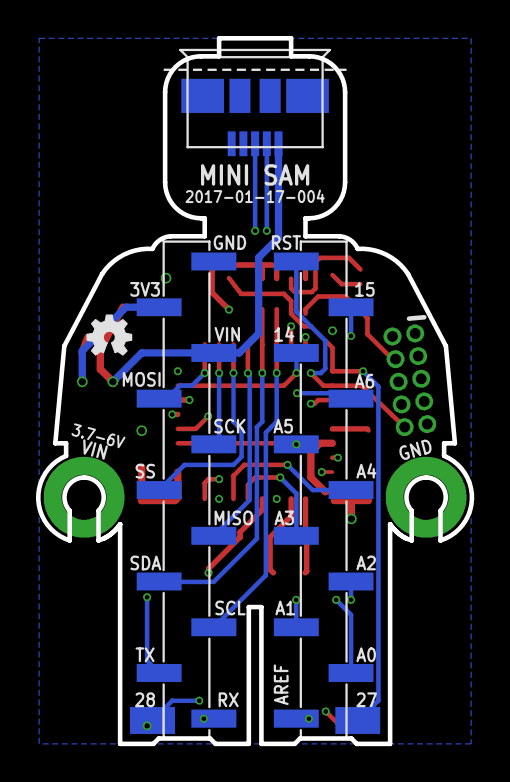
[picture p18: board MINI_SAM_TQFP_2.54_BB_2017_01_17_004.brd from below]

Board: 4 copper layers, 24.1 x 39.2 mm, 29 parts (6 on the bottom side), 34 nets.

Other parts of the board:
U$1, U$2: OSHW-LOGO-MINI

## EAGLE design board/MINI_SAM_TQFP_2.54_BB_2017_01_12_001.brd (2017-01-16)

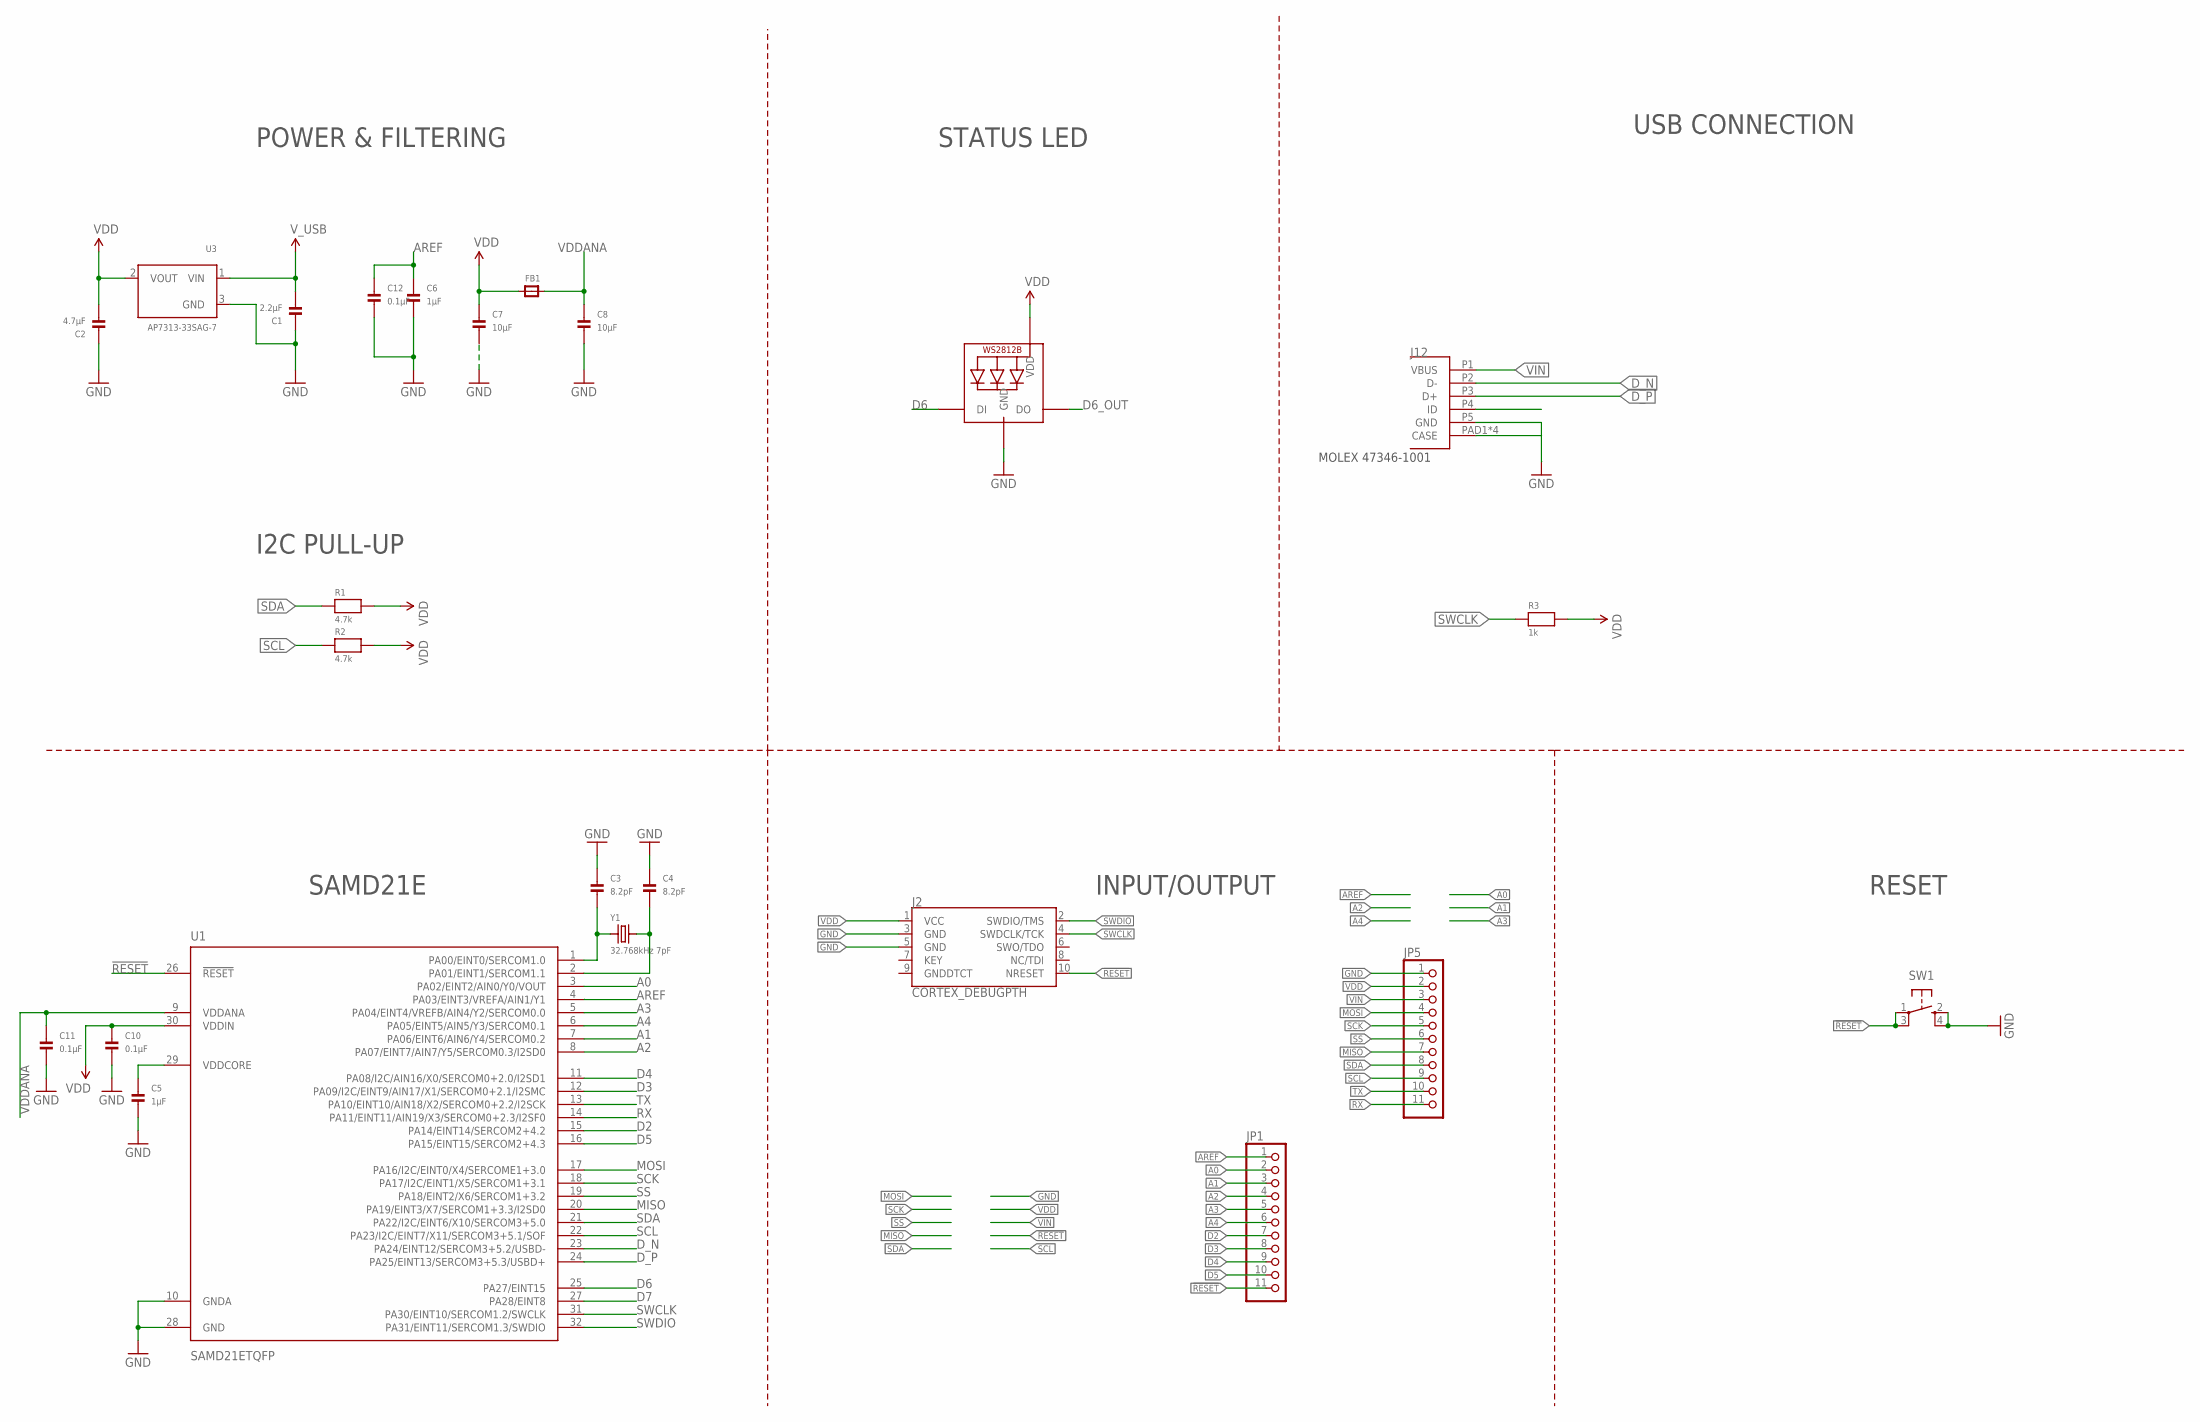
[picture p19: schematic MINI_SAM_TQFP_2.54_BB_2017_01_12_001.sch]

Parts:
C1: 2.2µF; _0805MP
C2: 4.7µF; _0805MP
C3, C4: 8.2pF; _0805MP
C5, C6: 1µF; _0805MP
C7, C8: 10µF; _0805MP
C10, C11, C12: 0.1µF; _0805MP
FB1: FERRITE_0805MP; _0805MP
J2: CORTEX_DEBUGPTH; 2X5-PTH-1.27MM
J12: MOLEX_47346-100147346; MOLEX_47346-1001
JP1, JP5: PINHD-1X111X11_SMT; 1X11_SMT
R1, R2: 4.7k; _0805MP
R3: 1k; _0805MP
STATUS: WS2812B3535; LED3535
SW1: SPST_TACT-KMR2; KMR2
U1: SAMD21ETQFP; TQFP32-08
U3: AP7313-33SAG-7; SOT23-R
Y1: 32.768kHz 7pF; _0805MP

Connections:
!RESET: J2.10 (NRESET), JP1.11, SW1.1, SW1.3 (P1), U1.26 (!RESET)
A0: JP1.2, U1.3 (PA02/EINT2/AIN0/Y0/VOUT)
A1: JP1.3, U1.7 (PA06/EINT6/AIN6/Y4/SERCOM0.2)
A2: JP1.4, U1.8 (PA07/EINT7/AIN7/Y5/SERCOM0.3/I2SD0)
A3: JP1.5, U1.5 (PA04/EINT4/VREFB/AIN4/Y2/SERCOM0.0)
A4: JP1.6, U1.6 (PA05/EINT5/AIN5/Y3/SERCOM0.1)
AREF: C6.1, C12.1, JP1.1, U1.4 (PA03/EINT3/VREFA/AIN1/Y1)
D2: JP1.7, U1.15 (PA14/EINT14/SERCOM2+4.2)
D3: JP1.8, U1.12 (PA09/I2C/EINT9/AIN17/X1/SERCOM0+2.1/I2S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)
D4: JP1.9, U1.11 (PA08/I2C/AIN16/X0/SERCOM0+2.0/I2SD1)
D5: JP1.10, U1.16 (PA15/EINT15/SERCOM2+4.3)
D6: STATUS.1 (DI), U1.25 (PA27/EINT15)
D6_OUT: STATUS.3 (DO)
D7: U1.27 (PA28/EINT8)
D_N: J12.P2 (D-), U1.23 (PA24/EINT12/SERCOM3+5.2/USBD-)
D_P: J12.P3 (D+), U1.24 (PA25/EINT13/SERCOM3+5.3/USBD+)
GND: C1.1, C2.1, C3.1, C4.1, C5.2, C6.2, C7.2, C8.2, C10.2, C11.2, C12.2, J2.3 (GND), J2.5 (GND), J12.P5 (GND), J12.PAD1 (CASE), J12.PAD2 (CASE), J12.PAD3 (CASE), J12.PAD4 (CASE), JP5.1, STATUS.4 (GND), SW1.2 (S), SW1.4 (S1), U1.10 (GNDA), U1.28 (GND), U3.3 (GND)
MISO: JP5.7, U1.20 (PA19/EINT3/X7/SERCOM1+3.3/I2SD0)
MOSI: JP5.4, U1.17 (PA16/I2C/EINT0/X4/SERCOME1+3.0)
unnamed: C3.2, U1.1 (PA00/EINT0/SERCOM1.0), Y1.1
unnamed: C4.2, U1.2 (PA01/EINT1/SERCOM1.1), Y1.2
unnamed: C5.1, U1.29 (VDDCORE)
RX: JP5.11, U1.14 (PA11/EINT11/AIN19/X3/SERCOM0+2.3/I2SF0)
SCK: JP5.5, U1.18 (PA17/I2C/EINT1/X5/SERCOM1+3.1)
SCL: JP5.9, R2.1, U1.22 (PA23/I2C/EINT7/X11/SERCOM3+5.1/SOF)
SDA: JP5.8, R1.1, U1.21 (PA22/I2C/EINT6/X10/SERCOM3+5.0)
SS: JP5.6, U1.19 (PA18/EINT2/X6/SERCOM1+3.2)
SWCLK: J2.4 (SWDCLK/TCK), R3.1, U1.31 (PA30/EINT10/SERCOM1.2/SWCLK)
SWDIO: J2.2 (SWDIO/TMS), U1.32 (PA31/EINT11/SERCOM1.3/SWDIO)
TX: JP5.10, U1.13 (PA10/EINT10/AIN18/X2/SERCOM0+2.2/I2SCK)
VDD: C2.2, C7.1, C10.1, FB1.1, J2.1 (VCC), JP5.2, R1.2, R2.2, R3.2, STATUS.2 (VDD), U1.30 (VDDIN), U3.2 (VOUT)
VDDANA: C8.1, C11.1, FB1.2, U1.9 (VDDANA)
VIN: C1.2, J12.P1 (VBUS), JP5.3, U3.1 (VIN)

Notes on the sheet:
INPUT/OUTPUT
RESET
POWER & FILTERING
SAMD21E
STATUS LED
USB CONNECTION
I2C PULL-UP
MOLEX 47346-1001

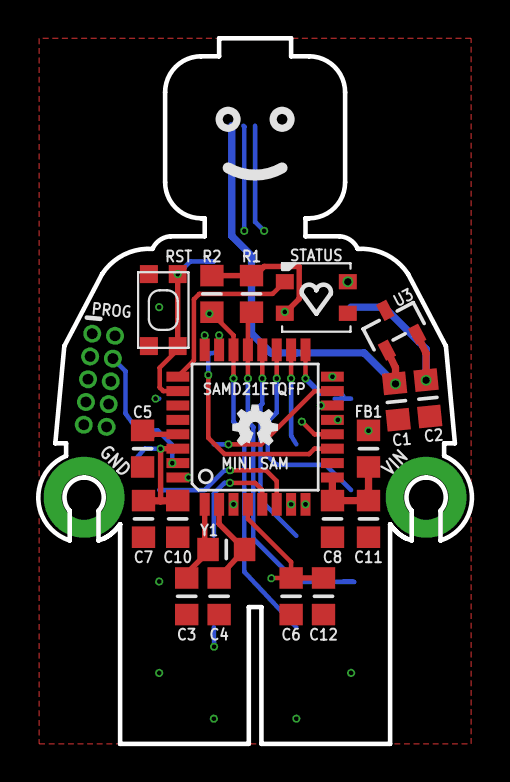
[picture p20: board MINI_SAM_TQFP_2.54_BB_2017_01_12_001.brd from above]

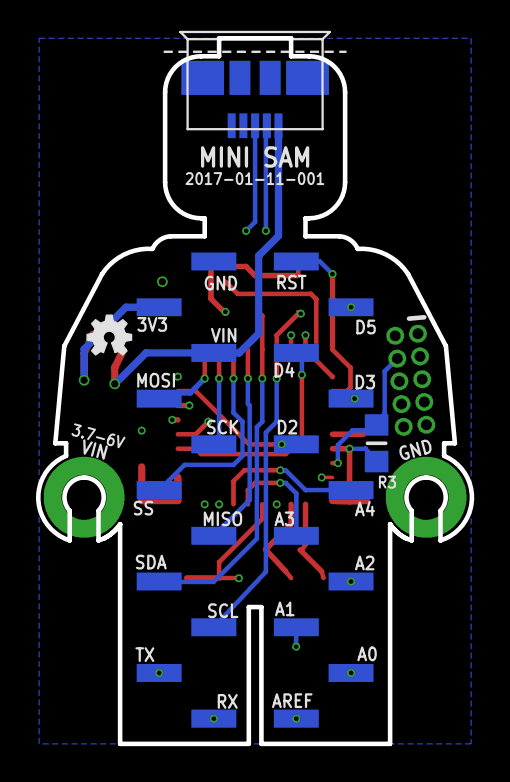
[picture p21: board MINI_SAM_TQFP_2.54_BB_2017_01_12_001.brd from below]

Board: 4 copper layers, 24.1 x 39.2 mm, 26 parts (5 on the bottom side), 31 nets.

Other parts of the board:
U$1, U$2: OSHW-LOGO-MINI

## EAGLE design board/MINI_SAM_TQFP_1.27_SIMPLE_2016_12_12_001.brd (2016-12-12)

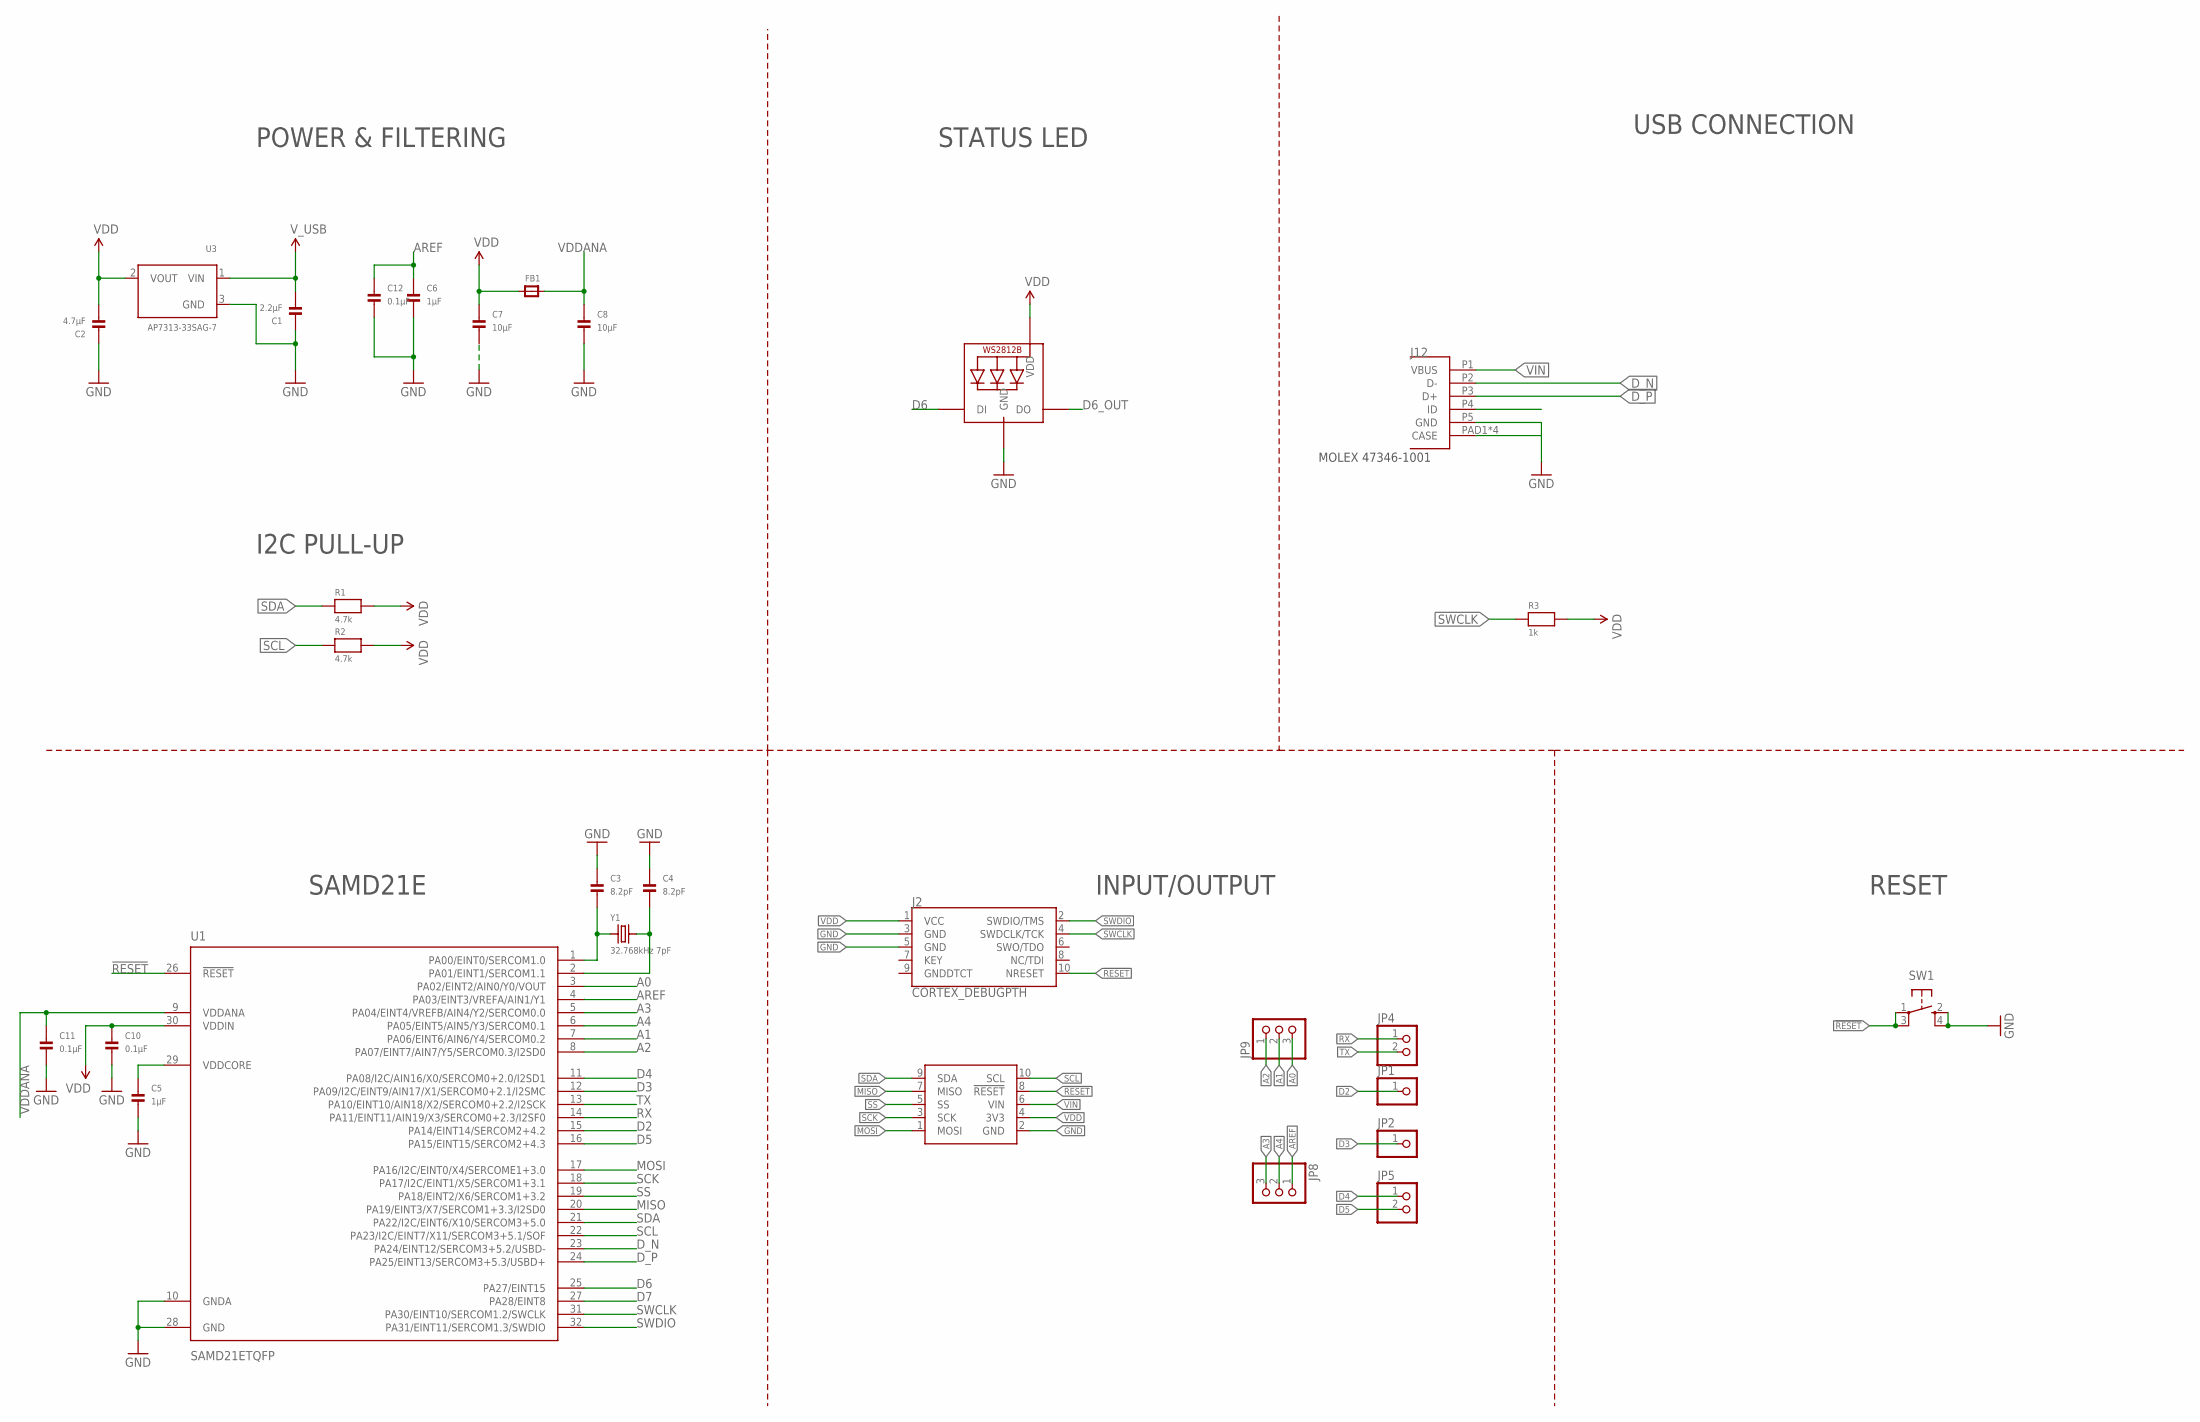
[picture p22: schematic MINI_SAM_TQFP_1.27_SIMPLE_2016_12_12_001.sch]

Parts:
C1: 2.2µF; _0805MP
C2: 4.7µF; _0805MP
C3, C4: 8.2pF; _0805MP
C5, C6: 1µF; _0805MP
C7, C8: 10µF; _0805MP
C10, C11, C12: 0.1µF; _0805MP
FB1: FERRITE_0805MP; _0805MP
J2: CORTEX_DEBUGPTH; 2X5-PTH-1.27MM
J12: MOLEX_47346-100147346; MOLEX_47346-1001
JP1, JP2: HEADER-1X1ROUND; 1X01_ROUND
JP4, JP5: HEADER-1X2ROUND; 1X02_ROUND
JP8, JP9: HEADER-1X3ROUND; 1X03_ROUND
R1, R2: 4.7k; _0805MP
R3: 1k; _0805MP
STATUS: WS2812B3535; LED3535
SW1: SPST_TACT-KMR2; KMR2
U1: SAMD21ETQFP; TQFP32-08
U3: AP7313-33SAG-7; SOT23-R
U$3: MINI_SAM_10_PIN; M50-360XXXX
Y1: 32.768kHz 7pF; _0805MP

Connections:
!RESET: J2.10 (NRESET), SW1.1, SW1.3 (P1), U1.26 (!RESET), U$3.8 (!RESET)
A0: JP9.3, U1.3 (PA02/EINT2/AIN0/Y0/VOUT)
A1: JP9.2, U1.7 (PA06/EINT6/AIN6/Y4/SERCOM0.2)
A2: JP9.1, U1.8 (PA07/EINT7/AIN7/Y5/SERCOM0.3/I2SD0)
A3: JP8.3, U1.5 (PA04/EINT4/VREFB/AIN4/Y2/SERCOM0.0)
A4: JP8.2, U1.6 (PA05/EINT5/AIN5/Y3/SERCOM0.1)
AREF: C6.1, C12.1, JP8.1, U1.4 (PA03/EINT3/VREFA/AIN1/Y1)
D2: JP1.1, U1.15 (PA14/EINT14/SERCOM2+4.2)
D3: JP2.1, U1.12 (PA09/I2C/EINT9/AIN17/X1/SERCOM0+2.1/I2S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)
D4: JP5.1, U1.11 (PA08/I2C/AIN16/X0/SERCOM0+2.0/I2SD1)
D5: JP5.2, U1.16 (PA15/EINT15/SERCOM2+4.3)
D6: STATUS.1 (DI), U1.25 (PA27/EINT15)
D6_OUT: STATUS.3 (DO)
D7: U1.27 (PA28/EINT8)
D_N: J12.P2 (D-), U1.23 (PA24/EINT12/SERCOM3+5.2/USBD-)
D_P: J12.P3 (D+), U1.24 (PA25/EINT13/SERCOM3+5.3/USBD+)
GND: C1.1, C2.1, C3.1, C4.1, C5.2, C6.2, C7.2, C8.2, C10.2, C11.2, C12.2, J2.3 (GND), J2.5 (GND), J12.P5 (GND), J12.PAD1 (CASE), J12.PAD2 (CASE), J12.PAD3 (CASE), J12.PAD4 (CASE), STATUS.4 (GND), SW1.2 (S), SW1.4 (S1), U1.10 (GNDA), U1.28 (GND), U3.3 (GND), U$3.2 (GND)
MISO: U1.20 (PA19/EINT3/X7/SERCOM1+3.3/I2SD0), U$3.7 (MISO)
MOSI: U1.17 (PA16/I2C/EINT0/X4/SERCOME1+3.0), U$3.1 (MOSI)
unnamed: C3.2, U1.1 (PA00/EINT0/SERCOM1.0), Y1.1
unnamed: C4.2, U1.2 (PA01/EINT1/SERCOM1.1), Y1.2
unnamed: C5.1, U1.29 (VDDCORE)
RX: JP4.1, U1.14 (PA11/EINT11/AIN19/X3/SERCOM0+2.3/I2SF0)
SCK: U1.18 (PA17/I2C/EINT1/X5/SERCOM1+3.1), U$3.3 (SCK)
SCL: R2.1, U1.22 (PA23/I2C/EINT7/X11/SERCOM3+5.1/SOF), U$3.10 (SCL)
SDA: R1.1, U1.21 (PA22/I2C/EINT6/X10/SERCOM3+5.0), U$3.9 (SDA)
SS: U1.19 (PA18/EINT2/X6/SERCOM1+3.2), U$3.5 (SS)
SWCLK: J2.4 (SWDCLK/TCK), R3.1, U1.31 (PA30/EINT10/SERCOM1.2/SWCLK)
SWDIO: J2.2 (SWDIO/TMS), U1.32 (PA31/EINT11/SERCOM1.3/SWDIO)
TX: JP4.2, U1.13 (PA10/EINT10/AIN18/X2/SERCOM0+2.2/I2SCK)
VDD: C2.2, C7.1, C10.1, FB1.1, J2.1 (VCC), R1.2, R2.2, R3.2, STATUS.2 (VDD), U1.30 (VDDIN), U3.2 (VOUT), U$3.4 (3V3)
VDDANA: C8.1, C11.1, FB1.2, U1.9 (VDDANA)
VIN: C1.2, J12.P1 (VBUS), U3.1 (VIN), U$3.6 (VIN)

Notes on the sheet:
INPUT/OUTPUT
RESET
POWER & FILTERING
SAMD21E
STATUS LED
USB CONNECTION
I2C PULL-UP
MOLEX 47346-1001

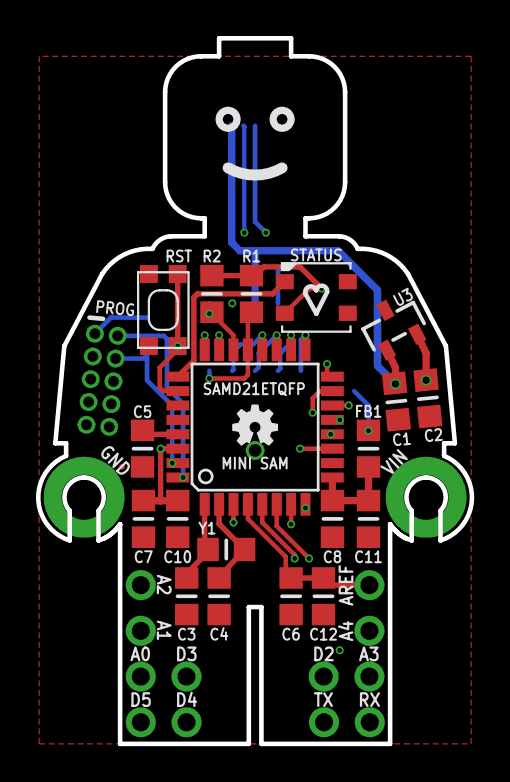
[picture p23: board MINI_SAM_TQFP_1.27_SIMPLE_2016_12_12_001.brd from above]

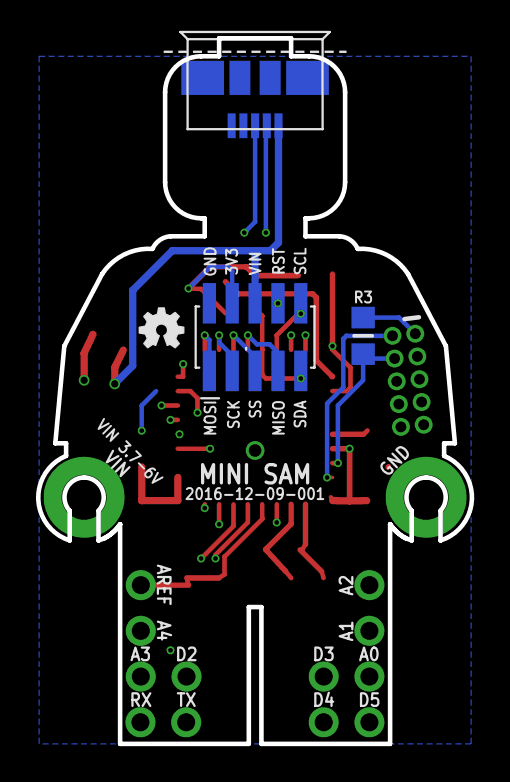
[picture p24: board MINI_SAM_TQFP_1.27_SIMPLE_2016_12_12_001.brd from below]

Board: 4 copper layers, 24.1 x 39.2 mm, 31 parts (4 on the bottom side), 31 nets.

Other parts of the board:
U$1, U$2: OSHW-LOGO-MINI

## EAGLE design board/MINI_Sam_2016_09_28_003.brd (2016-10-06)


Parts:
C1: 2.2µF; _0805MP
C2: 4.7µF; _0805MP
C3, C4: 8.2pF; _0805MP
C5, C6: 1µF; _0805MP
C7, C8: 10µF; _0805MP
C9: .1µF; _0805MP
C10, C11, C12: 0.1µF; _0805MP
C13: 4700pF; _0805MP
D1: 20V 1A; _0805MP
FB1: FERRITE_0805MP; _0805MP
J1: CORTEX_DEBUGPTH; 2X5-PTH-1.27MM
J12: MOLEX_47346-100147346; MOLEX_47346-1001
JP3: HEADER-1X6ROUND; 1X06_ROUND
JP4: HEADER-1X4ROUND; 1X04_ROUND
JP7: HEADER-1X5ROUND; 1X05_ROUND
JP8, JP9: HEADER-1X3ROUND; 1X03_ROUND
LED: WS2812B3535; LED3535
R1, R2: 4.7k; _0805MP
R3: 330; _0805MP
R4: 10k; _0805MP
R5: 1k; _0805MP
R6: 1M; _0805MP
SW1: SPST_TACT-KMR2; KMR2
U1: SAMD21E; QFN32
U2: USBLC6-2; SOT23-6L
U3: AP7313-33SAG-7; SOT23-R
Y1: 32.768kHz 7pF; _0805MP

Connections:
!RESET: J1.10 (NRESET), R3.1, U1.26 (!RESET)
A0: JP9.3, U1.3 (PA02/EINT2/AIN0/Y0/VOUT)
A1: JP9.2, U1.7 (PA06/EINT6/AIN6/Y4/SERCOM0.2)
A2: JP9.1, U1.8 (PA07/EINT7/AIN7/Y5/SERCOM0.3/I2SD0)
A3: JP8.3, U1.5 (PA04/EINT4/VREFB/AIN4/Y2/SERCOM0.0)
A4: JP8.2, U1.6 (PA05/EINT5/AIN5/Y3/SERCOM0.1)
AREF: C6.1, C12.1, JP8.1, U1.4 (PA03/EINT3/VREFA/AIN1/Y1)
D2: JP3.4, U1.15 (PA14/EINT14/SERCOM2+4.2)
D3: JP3.3, U1.12 (PA09/I2C/EINT9/AIN17/X1/SERCOM0+2.1/I2S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)
D4: JP3.2, U1.11 (PA08/I2C/AIN16/X0/SERCOM0+2.0/I2SD1)
D5: JP3.1, U1.16 (PA15/EINT15/SERCOM2+4.3)
D6: LED.1 (DI), U1.25 (PA27/EINT15)
D6_OUT: LED.3 (DO)
D7: U1.27 (PA28/EINT8)
D+: J12.P3 (D+), U2.3 (I/O2)
D-: J12.P2 (D-), U2.1 (I/O1)
D_N: U1.23 (PA24/EINT12/SERCOM3+5.2/USBD-), U2.6 (I/O1)
D_P: U1.24 (PA25/EINT13/SERCOM3+5.3/USBD+), U2.4 (I/O2)
GND: C1.1, C2.1, C3.1, C4.1, C5.2, C6.2, C7.2, C8.2, C9.1, C10.2, C11.2, C12.2, C13.2, J1.3 (GND), J1.5 (GND), J1.7 (KEY), J1.9 (GNDDTCT), J12.P5 (GND), JP7.1, LED.4 (GND), R6.1, SW1.2 (S), SW1.4 (S1), U1.10 (GNDA), U1.28 (GND), U3.3 (GND)
MISO: JP4.2, U1.20 (PA19/EINT3/X7/SERCOM1+3.3/I2SD0)
MOSI: JP4.3, U1.17 (PA16/I2C/EINT0/X4/SERCOME1+3.0)
unnamed: C3.2, U1.1 (PA00/EINT0/SERCOM1.0), Y1.1
unnamed: C9.2, R3.2, R4.2, SW1.1, SW1.3 (P1)
unnamed: C4.2, U1.2 (PA01/EINT1/SERCOM1.1), Y1.2
unnamed: C5.1, U1.29 (VDDCORE)
RX: JP3.6, U1.14 (PA11/EINT11/AIN19/X3/SERCOM0+2.3/I2SF0)
SCK: JP4.1, U1.18 (PA17/I2C/EINT1/X5/SERCOM1+3.1)
SCL: JP7.5, R2.1, U1.22 (PA23/I2C/EINT7/X11/SERCOM3+5.1/SOF)
SDA: JP7.4, R1.1, U1.21 (PA22/I2C/EINT6/X10/SERCOM3+5.0)
SHIELD: C13.1, J12.PAD1 (CASE), J12.PAD2 (CASE), J12.PAD3 (CASE), J12.PAD4 (CASE), R6.2, U2.2 (GND)
SS: JP4.4, U1.19 (PA18/EINT2/X6/SERCOM1+3.2)
SWCLK: J1.4 (SWDCLK/TCK), R5.1, U1.31 (PA30/EINT10/SERCOM1.2/SWCLK)
SWDIO: J1.2 (SWDIO/TMS), U1.32 (PA31/EINT11/SERCOM1.3/SWDIO)
TX: JP3.5, U1.13 (PA10/EINT10/AIN18/X2/SERCOM0+2.2/I2SCK)
VBUS: D1.1 (A), J12.P1 (VBUS), U2.5 (VBUS)
VDD: C2.2, C7.1, C10.1, FB1.1, J1.1 (VCC), JP7.2, LED.2 (VDD), R1.2, R2.2, R4.1, R5.2, U1.30 (VDDIN), U3.2 (VOUT)
VDDANA: C8.1, C11.1, FB1.2, U1.9 (VDDANA)
VIN: C1.2, D1.2 (C), JP7.3, U3.1 (VIN)

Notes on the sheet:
INPUT/OUTPUT
RESET
POWER & FILTERING
SAMD21E
USB
LED
DESIGNER:



Board: 4 copper layers, 24.0 x 38.5 mm, 35 parts (5 on the bottom side), 36 nets.

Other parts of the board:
U$1: OSHW-LOGO-M

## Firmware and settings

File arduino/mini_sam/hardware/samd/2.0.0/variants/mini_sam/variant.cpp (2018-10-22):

/*
  Copyright (c) 2014-2015 Arduino LLC.  All right reserved.

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
  You should have received a copy of the GNU Lesser General Public
  License along with this library; if not, write to the Free Software
  Foundation, Inc., 51 Franklin St, Fifth Floor, Boston, MA  02110-1301  USA
*/

/*
  Modified 17 January 2017 by Benjamin Shockley
     for Mini SAM D21E
*/


/*  Pins descriptions for Mini SAM
 *
 * | Arduino Pin Number |    Silkscreen    |  PIN   |   Alt. Function   | Comments (! means unavailable with this variant)
 * +--------------------+------------------+--------+-------------------+-------------------------------------------------
 * | --                 | --               |  PA00  | Xin32             | Xin32
 * | --                 | --               |  PA01  | Xout32            | Xout32
 * | 2                  | A0               |  PA02  |                   | EIC/EXTINT[2] ADC/AIN[0] PTC/Y[0] DAC/VOUT
 * | 3                  | AREF             |  PA03  | REFA              | EIC/EXTINT[3] REF/ADC/VREFA REF/DAC/VREFA ADC/AIN[1] PTC/Y[1]
 * | 4                  | ~A3              |  PA04  |                   | EIC/EXTINT[4] REF/ADC/VREFB ADC/AIN[4] AC/AIN[0] PTC/Y[2] !SERCOM0/PAD[0] TCC0/WO[0]
 * | 5                  | ~A4              |  PA05  |                   | EIC/EXTINT[5] ADC/AIN[5] AC/AIN[1] PTC/Y[3] !SERCOM0/PAD[1] TCC0/WO[1]
 * | 6                  | ~A1              |  PA06  |                   | !EIC/EXTINT[6] ADC/AIN[6] AC/AIN[2] PTC/Y[4] !SERCOM0/PAD[2] TCC1/WO[0]
 * | 7                  | ~A2              |  PA07  | Voltage Divider   | !EIC/EXTINT[7] ADC/AIN[7] AC/AIN[3] PTC/Y[5] !SERCOM0/PAD[3] TCC1/WO[1]
 * | 8                  | ~A5              |  PA08  |                   | EIC/NMI ADC/AIN[16] PTC/X[0] !SERCOM0/PAD[0] !SERCOM2/PAD[0] !TCC0/WO[0] TCC1/WO[2]
 * | 9                  | ~A6              |  PA09  |                   | EIC/EXTINT[9] ADC/AIN[17] PTC/X[1] !SERCOM0/PAD[1] !SERCOM2/PAD[1] !TCC0/WO[1] TCC1/WO[3]
 * | 10                 | TX               |  PA10  | TX                | !EIC/EXTINT[10] ADC/AIN[18] PTC/X[2] SERCOM0/PAD[2] !SERCOM2/PAD[2] !TCC1/WO[0] TCC0/WO[2]
 * | 11                 | RX               |  PA11  | RX                | !EIC/EXTINT[11] ADC/AIN[19] PTC/X[3] SERCOM0/PAD[3] !SERCOM2/PAD[3] !TCC1/WO[1] TCC0/WO[3]
 * | 14                 | ~14              |  PA14  |                   | EIC/EXTINT[14] SERCOM2/PAD[2] !TC3/WO[0] TCC0/WO[4]
 * | 15                 | ~15              |  PA15  | LED               | !EIC/EXTINT[15] SERCOM2/PAD[3] !TC3/WO[1] TCC0/WO[5]
 * | --                 | RST              |  ----  |                   | Reset
 * | --                 | Gnd              |  ----  |                   | Ground
 * | --                 | VDD              |  ----  |                   | VDD 3.3V
 * | --                 | Vin              |  ----  |                   | Vin 3.7V - 6.0V
 * | 16                 | ~MOSI            |  PA16  | SPI MOSI          | EIC/EXTINT[0] PTC/X[4] SERCOM1/PAD[0] !SERCOM3/PAD[0] TCC2/WO[0] !TCC0/WO[6]
 * | 17                 | ~SCK             |  PA17  | SPI SCK           | EIC/EXTINT[1] PTC/X[5] SERCOM1/PAD[1] !SERCOM3/PAD[1] TCC2/WO[1] !TCC0/WO[7]
 * | 18                 | ~SS              |  PA18  | SPI SS            | EIC/EXTINT[2] PTC/X[6] SERCOM1/PAD[2] !SERCOM3/PAD[2] TC3/WO[0] !TCC0/WO[2]
 * | 19                 | ~MISO            |  PA19  | SPI MISO          | EIC/EXTINT[3] PTC/X[7] SERCOM1/PAD[3] !SERCOM3/PAD[3] TC3/WO[1] !TCC0/WO[3]
 * | 22                 | ~SDA             |  PA22  | I2C/SDA w/pullup  | EIC/EXTINT[6] PTC/X[10] SERCOM3/PAD[0] !SERCOM5/PAD[0] TC4/WO[0] !TCC0/WO[4]
 * | 23                 | ~SCL             |  PA23  | I2C/SCL w/pullup  | EIC/EXTINT[7] PTC/X[11] SERCOM3/PAD[1] !SERCOM5/PAD[1] TC4/WO[1] !TCC0/WO[5]
 * | --                 | --               |  PA24  | USB Data -        | USB Connector
 * | --                 | --               |  PA25  | USB Data +        | USB Connector
 * | 27                 | 27               |  PA27  | RGB LED           | EIC/EXTINT[15] WS2812B LED
 * | 28                 | 28               |  PA28  |                   | EIC/EXTINT[15] Button
 * | 30                 | --               |  PA30  | SWD CLK           | EIC/EXTINT[10] !SERCOM1/PAD[2] TCC1/WO[0] SWD CLK
 * | 31                 | --               |  PA31  | SWD IO            | EIC/EXTINT[11] !SERCOM1/PAD[3] TCC1/WO[1] SWD IO
 * +--------------------+------------------+--------+-------------------+-------------------------------------------------
 *
 * You may use Arduino pin numbers ranging from 0 to 31.
 * For example, use pinMode(14, OUTPUT) to set the LED pin (marked as 14) as an output.
 * However, the following Arduino pin numbers are not mapped to a physical pin: 0, 1, 12, 13, 20, 21, 24, 25, 26, and 29.
 * Pins 0 and 1 are used by the 32.768KHz crystal which in turn is used by the Arduino core (the 16MHz crystal is unused by Arduino).
 * Pins 24 and 25 are in use by USB (USB_NEGATIVE and USB_POSITIVE).
 * Pin 27 is in use controlling the build in WS1812B RGB LED.
 * Pin 28 is not connected.
 * Pins 30 and 31 are in use by SWD Programming Port - Could eventually be utilized.
 */


#include "variant.h"
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

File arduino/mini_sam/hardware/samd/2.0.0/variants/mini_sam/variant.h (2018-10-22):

/*
  Copyright (c) 2014-2015 Arduino LLC.  All right reserved.
  This library is free software; you can redistribute it and/or
  modify it under the terms of the GNU Lesser General Public
  License as published by the Free Software Foundation; either
  version 2.1 of the License, or (at your option) any later version.
  This library is distributed in the hope that it will be useful,
  but WITHOUT ANY WARRANTY; without even the implied warranty of
  MERCHANTABILITY or FITNESS FOR A PARTICULAR PURPOSE.
  See the GNU Lesser General Public License for more details.
  You should have received a copy of the GNU Lesser General Public
  License along with this library; if not, write to the Free Software
  Foundation, Inc., 51 Franklin St, Fifth Floor, Boston, MA  02110-1301  USA
*/

/*
  Modified 17 January 2017 by Benjamin Shockley
     for Mini SAM SAMD21E
*/

#ifndef _VARIANT_MINI_SAM
#define _VARIANT_MINI_SAM


/*----------------------------------------------------------------------------
 *        Definitions
 *----------------------------------------------------------------------------*/

/** Frequency of the board main oscillator */
#define VARIANT_MAINOSC		(32768ul)

/** Master clock frequency */
#define VARIANT_MCK			  (48000000ul)

/*----------------------------------------------------------------------------
 *        Headers
 *----------------------------------------------------------------------------*/

#include "WVariant.h"

#ifdef __cplusplus
#include "SERCOM.h"
#include "Uart.h"
#endif // __cplusplus

#ifdef __cplusplus
extern "C"
{
#endif // __cplusplus

/*----------------------------------------------------------------------------
 *        Pins
 *----------------------------------------------------------------------------*/

// Number of pins defined in PinDescription array
#define NUM_PIN_DESCRIPTION_ENTRIES     (32u)

#define PINS_COUNT           (32u)
#define NUM_DIGITAL_PINS     (32u)
#define NUM_ANALOG_INPUTS    (10u)
#define NUM_ANALOG_OUTPUTS   (1u)
#define analogInputToDigitalPin(p)  (p)

#define digitalPinToPort(P)        ( &(PORT->Group[g_APinDescription[P].ulPort]) )
#define digitalPinToBitMask(P)     ( 1 << g_APinDescription[P].ulPin )
//#define analogInPinToBit(P)        ( )
#define portOutputRegister(port)   ( &(port->OUT.reg) )
#define portInputRegister(port)    ( &(port->IN.reg) )
#define portModeRegister(port)     ( &(port->DIR.reg) )
#define digitalPinHasPWM(P)        ( g_APinDescription[P].ulPWMChannel != NOT_ON_PWM || g_APinDescription[P].ulTCChannel != NOT_ON_TIMER )

/*
 * digitalPinToTimer(..) is AVR-specific and is not defined for SAMD
 * architecture. If you need to check if a pin supports PWM you must
 * use digitalPinHasPWM(..).
 *
 * https://github.com/arduino/Arduino/issues/1833
 */
// #define digitalPinToTimer(P)

/* LEDs
 * The LED is connected to PIN 15.
 */
#define PIN_LED_13           (15u)
#define PIN_LED              PIN_LED_13
#define LED_BUILTIN          PIN_LED_13

/* Buttons
 * Reset Button is not connected to Arduino Pins
 * Builtin Button is connected to Pin 28
 */
#define BUTTON_BUILTIN       (28u)


/*
 * Analog pins
 */
#define PIN_AREF             (3ul)
#define PIN_A0               (2ul)
#define PIN_A1               (6ul)
#define PIN_A2               (7ul)
#define PIN_A3               (4ul)
#define PIN_A4               (5ul)
#define PIN_A5               (8ul)
#define PIN_A6               (9ul)
#define PIN_A7               (10ul)
#define PIN_A8               (11ul)
#define PIN_DAC0             (2ul)

static const uint8_t AREF = PIN_AREF;
static const uint8_t A0   = PIN_A0;
static const uint8_t A1   = PIN_A1;
static const uint8_t A2   = PIN_A2;
static const uint8_t A3   = PIN_A3;
static const uint8_t A4   = PIN_A4;
static const uint8_t A5   = PIN_A5;
static const uint8_t A6   = PIN_A6;
static const uint8_t A7   = PIN_A7;
static const uint8_t A8   = PIN_A8;
static const uint8_t DAC0 = PIN_DAC0;

#define ADC_RESOLUTION		12

#define REMAP_ANALOG_PIN_ID	while(0)
// #define REMAP_ANALOG_PIN_ID	if ( ulPin < A0 ) ulPin += A0

/* Set default analog voltage reference */
#define VARIANT_AR_DEFAULT	AR_DEFAULT

/* Reference voltage pins (define even if not enabled with PIN_ATTR_REF in the PinDescription table) */
#define REFA_PIN    (3ul)


/*
 * Serial interfaces
 */
// Serial
#define PIN_SERIAL1_RX       (11ul)
#define PIN_SERIAL1_TX       (10ul)
#define PAD_SERIAL1_TX       (UART_TX_PAD_2)
#define PAD_SERIAL1_RX       (SERCOM_RX_PAD_3)


/*
 * SPI Interfaces
 */
#define SPI_INTERFACES_COUNT 1

#define PIN_SPI_MISO         (19u)
#define PIN_SPI_MOSI         (16u)
#define PIN_SPI_SCK          (17u)
#define PIN_SPI_SS           (18u)
#define PERIPH_SPI           sercom1
#define PAD_SPI_TX           SPI_PAD_2_SCK_3
#define PAD_SPI_RX           SERCOM_RX_PAD_0

static const uint8_t SS	  = PIN_SPI_SS ;	// The SERCOM SS PAD is available on this pin but HW SS isn't used. Set here only for reference.
static const uint8_t MOSI = PIN_SPI_MOSI ;
static const uint8_t MISO = PIN_SPI_MISO ;
static const uint8_t SCK  = PIN_SPI_SCK ;


/*
 * Wire Interfaces
 */
#define WIRE_INTERFACES_COUNT 1

#define PIN_WIRE_SDA         (22u)
#define PIN_WIRE_SCL         (23u)
#define PERIPH_WIRE          sercom3
#define WIRE_IT_HANDLER      SERCOM3_Handler

static const uint8_t SDA = PIN_WIRE_SDA;
static const uint8_t SCL = PIN_WIRE_SCL;


/*
 * USB
 */
#define PIN_USB_DM                      (24ul)
#define PIN_USB_DP                      (25ul)
#define PIN_USB_HOST_ENABLE             (14ul)
#define PIN_USB_HOST_ENABLE_VALUE	HIGH

#ifdef __cplusplus
}
#endif


/*----------------------------------------------------------------------------
 *        Arduino objects - C++ only
 *----------------------------------------------------------------------------*/

#ifdef __cplusplus

/*	=========================
 *	===== SERCOM DEFINITION
 *	=========================
*/
extern SERCOM sercom0;
extern SERCOM sercom1;
extern SERCOM sercom2;
extern SERCOM sercom3;

extern Uart Serial1;

#endif
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

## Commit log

2016-10-06 Added PDF of Schematic
2016-10-06 Add SCH and BRD Files
    Initial Files added.
    [MINI_Sam_2016_09_28_003.brd, MINI_Sam_2016_09_28_003.sch]
2016-10-25 New Boards
    Added new boards with a better defined boarder, and added a 2mm pitch, 2x6 SMD header option for USB/Programming/SDA/SPI.
    [MINI_Sam_2016_10_24_002.brd, MINI_Sam_2016_10_24_002.sch]
2016-10-25 Added MINI SAM #2 Schematic
    PDF of schematic for MINI SAM with 2mm header.
2016-10-25 Update for Board Links
    Added links to shared projects on OSHPark.
2016-12-09 Uploaded TQFP SIMPLE
    MINI SAM with TQFP SAMD21E and removed unnecessary USB protection and reset debounce.
    [MINI_SAM_TQFP_8-Pin_SIMPLE_2016_12_09_001.brd, MINI_SAM_TQFP_8-Pin_SIMPLE_2016_12_09_001.sch]
2016-12-09 Uploaded TQFP SIMPLE SCHEMATIC
2016-12-12 Add 1.27mm Pitch SIMPLE
2016-12-12 Added 1.27mm Pitch SIMPLE
    [MINI_SAM_TQFP_1.27_SIMPLE_2016_12_12_001.brd, MINI_SAM_TQFP_1.27_SIMPLE_2016_12_12_001.sch]
2017-01-16 Added 2.54_BB Version
    [MINI_SAM_TQFP_2.54_BB_2017_01_12_001.brd, MINI_SAM_TQFP_2.54_BB_2017_01_12_001.sch]
2017-01-26 Create README.md
    Initial Creation - added board via upload.
2017-01-26 Add files via upload
    Added the PDF schematic.
2017-01-26 Update README.md
    Added clarity and fixed a couple PIN assignment mistakes.
2017-01-27 Cleanup and PIN 28 Change
    Formatting clean up and reference to PIN28 cleaned up.
2017-01-27 Fixed LED_PIN
    Fixed LED_PIN to reference PIN 15 instead of PIN 14.
    [variant.h]
2017-01-27 Fixed LED PIN
    Fixed reference to LED PIN from 14 to 15.
2017-01-27 Updated Internal Layer
    Updated one of the internal layers to include a ground plane for better grounding.
    [MINI_SAM_2017-01-001.brd]
2017-01-27 Updated to -002
    [MINI_SAM_2017-01-002.brd, MINI_SAM_2017-01-002.sch]
2017-02-03 Create minifigure.lbr
    Created the basic minifigure library. Add this library to your Eagle libraries to add a LEGO minifigure sized board outline with two vias for hands.
2017-02-03 Added -010 Version
    Minor Changes to BOM - Voltage Regulator and USB Protection. Added a couple minor aesthetic changes as well. 1980's Space Man!
    [MINI_SAM_2017-01-010.brd, MINI_SAM_2017-01-010.sch]
2017-02-04 BOM for Oct 6th Minifigure-SAMD21E On OSHPARK
    BOM for Oct 6th Minifigure-SAMD21E On OSHPARK
2017-02-16 Added Builtin_Button removed Extra SERCOM
    Added definition for the built in Button attached to PIN 28 to be accessible via "BUTTON_BUILTIN".
    Removed SERCOM4 and SERCOM5 definitions as the SAMD21E does not have these SERCOMs.
2017-02-20 Added V12 to 2017-01
    Added V12 with minor cosmetic changes.
    [MINI_SAM_2017-01-012.brd, MINI_SAM_2017-01-012.sch]
2017-02-24 Update to I2C Jumper
    Fixed the I2C disconnect jumper.
    [MINI_SAM_2017-01-015.brd, MINI_SAM_2017-01-015.sch]
2018-10-22 Added v2.0.0
    [samd21e18a.cfg]

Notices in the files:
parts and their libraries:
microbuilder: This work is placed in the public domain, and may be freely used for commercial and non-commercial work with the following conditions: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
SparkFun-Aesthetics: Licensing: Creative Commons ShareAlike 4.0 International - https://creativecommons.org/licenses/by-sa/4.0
